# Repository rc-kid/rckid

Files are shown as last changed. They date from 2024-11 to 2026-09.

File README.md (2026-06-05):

# RCKid mk3

RCKid is an open‑source handheld console designed for young creators. It’s built to be the first piece of technology that feels truly personal to a child — not just a screen to consume, but a tool to imagine, build, and share. RCKid also supports kids in everyday tools like a clock, alarm, piggy bank, contacts, or music player. This balance of fun and function turns RCKid into a trusted companion, introducing kids to digital literacy, technology, and STEM skills in a way that grows with them. For more information, have a look at the [grand vision](VISION.md) 

Starting at age 5, kids can design sprites, tiles, and music inside native games, learning problem‑solving naturally through play. As they grow, RCKid will provide more and more complex ways of control (visual blocks, scratch-like blocks, C++, Full C++ SDK). For more details see [development ladder](LADDER.md).

A defining feature is RCKid’s cartridge system — not just for games, but for extending hardware. Cartridges can add Wi‑Fi for messaging, radios for mesh networking, JACDAC peripherals, IR remotes, or even exposed pins for DIY tinkering. Each cartridge carries its own firmware, making creations tangible, shareable, and hackable.

Powered by the RP2350 MCU (dual Cortex‑M33, 520KB RAM, PIO), RCKid combines raw performance with developer‑friendly design. It features a 2.8" IPS display at 60 FPS, stereo audio up to 48kHz, SD storage, RGB‑backlit controls, accelerometer, haptics, FM radio, and flexible power (USB‑C Li‑Ion or AAA batteries). Everything is built to be fun, approachable, and resilient.

## Technical Details

- RP2350 MCU from RaspberryPi that mixes raw power (520KB RAM, 2x Cortex M33 cores at 150MHz with overclocking possibility) and ease of use (C++ SDK, micropython). Further supported by great community and skillfully designed so that programming it is *fun* even for experienced developers (PIO)
- unique cartridge system: the firmware is not stored on the device, but in every cartridge. Cartridges can be swapped, shared, or reprogrammed with any computer easily. On top of the mandatory FLASH for the firmware, cartridges contain 8 high speed digital pins (HSTX, SPI, I2C, UART, PWM) and 2 analog pins to enable hardware tinkering
- 2.8" 320x240 IPS display with 65536 colors. Perfect for retro gaming and pixel art with enough catchy detail, but not too many pixels to design. 60 FPS refresh rate.
- 16bit stereo sound (headphones & mono speaker) with up to 48kHz playback. Powerful enough for MP3 playback
- SD card for media & settings, up to 64GB supported. FAT32 and exFAT filesystem 
- DPAD, A, B, Select and Start buttons with customizable RGB backlight
- 3 axis accelerometer with integrated pedometer
- rumbler for haptic feedback (simple motor)
- FM radio with RDS
- 1300mAh LiIon rechargeable battery with USB-C charging, or 3x AAA batteries, both options should give around 10 hours of active time. 

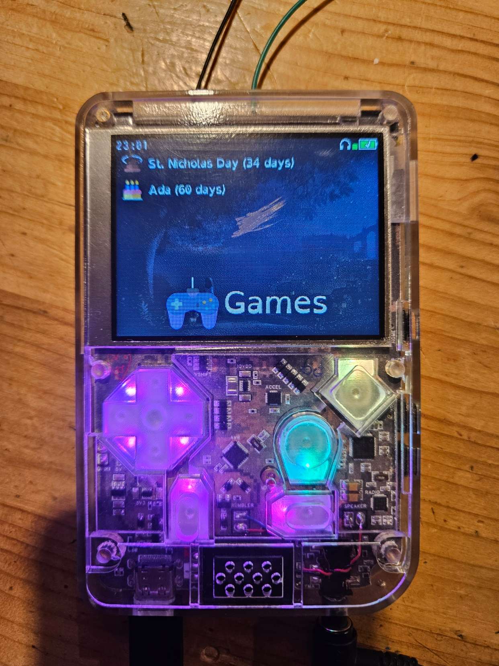
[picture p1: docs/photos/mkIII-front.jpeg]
RCKid mkIII RCKid prototype


## Development

> The readme is mostly about setting the project up and understanding its development & internal structure. 

RCKid supports different backends, including a fantasy backend that allows running RCKid cartridges virtually on the PC, and the mkIII backend that runs on the actual device. Each backend provides its own implementation of the hardware abstraction layer (defined in `sdk/include/rckid/hal.h`) as well as capabilities (see below).  The fantasy backend, also includes test target (`run-tests`) that runs unit tests for the SDK and selected cartridges. It emulates the hardware of the device, including the display & sound using raylib, SD card and LittleFS on the cartridge using dedicated iso files and the FatFS and LittleFS libraries, or native folders via virtual filesystem (where the filesystem API is implemented for normal files, bypassing the fs libraries altogether for convenience). The fantasy backend also supports emspcripten.

## Project Structure

The project is organized into a few top level folders that branch into subfolders where appropriate. This is reflected in the brief list below:

- `sdk` : the SDK code (common firmware for the device, backends, ATTiny MCU, etc.)
- `sdk/assets` : asset files in their natural form (images, sounds, etc.)
- `sdk/backend` : the supported backends (implementation of the hardware abstraction layer)
- `sdk/backend/fantasy` : the fantasy backend for RCKid. This allows running RCKid cartridges virtually on the PC
- `sdk/backend/mk3` : the RP2350 and the device specific code
- `sdk/backend/avr` : firmware for the ATTiny3217 MCU responsible for IO, power management, etc
- `sdk/include/rckid` : SDK headers to be included into cartridges (the SDK API). Some code in this folder, rest in subfolders
- `sdk/include/rckid/apps` : applications for RCKid (pedometer, audio player, clock, etc.)
- `sdk/include/rckid/audio` : audio recording / playback, codecs, etc.
- `sdk/include/rckid/capabilities` : extra hardware capabilities (WiFi, pedometer, flashlight, etc.)
- `sdk/include/rckid/game` : game engine with C++ and dynamic bindings for kids to create their own games
- `sdk/include/rckid/graphics` : basic graphics utilities (colors & representation, bitmaps, fonts, etc.)
- `sdk/include/rckid/ui` : simple UI widgets toolkit 
- `sdk/include/assets` : assets for the rckid converted to constexpr arrays to be included with cartridges
- `sdk/src` : C++ implementation for the files in `sdk/include`, same structure internally
- `sdk/test` : unit tests (see testing chapter below)
- `lib` : contains 3rd party libraries that are copied / cloned as part of the SDK (including pico-sdk and raylib). Do not change code in here except for the platform below
- `lib/platform` : custom headers for different platforms (desktop, rp2350, ATTiny3217, Arduino, ...) for basic HW features and cross-platform utilities
- `cartridges` : cartridges for the RCkid
- `cartridges/text` : cartridges specifically for test purposes
- `gbcemu` : Gameboy emulator implementation for RCKid
- `datasheets` contains copies of datasheets of the hardware used in RCKid
- `hardware` contains hardware related files, such as schematics, PCB layouts and case drawings
- `lego-remote` AVR firmware for a remote client to control lego bricks, at the moment just parked here from mkI

## Important Files

Non-code files:

- `README.md` : basic intro the the repository, build instructions, etc.
- `VISION.md` : the vision for the project, you can read this for context when discussing non-code, but necessary for the code itself
- `LADDER.md` : the learning ladder for the project, which I am implementing in the `sdk/include/rckid/game` folder (from asset editor for youngest kids to visual editor to blocks to code DSL to full SDK)
- `HARDWARE.md` : more details about the hardware design, useful forhardware related questions

Code files:

- `sdk/include/rckid/hal.h` : functions that *must* be implemented by each backend to support the basic features (display, power, sound, io, etc.)
- `sdk/include/memory.h` : own memory management including custom heap on the device and virtual custom heap in fantasy mode to track memory consumption accurately

## Building

Although there is technically nothing that should prevent building the software on Windows, only Linux is officially supported (actually Ubuntu 24.04 running on WSL:). The `setup-ubuntu.sh` must first be executed which installs all the required packages and sets up subprojects, etc. The project uses `cmake` as the build system. Generally I use out of tree builds, which can be found in `build` prefixed folder, such as:

- `build` : for the fantasy target
- `build-mk3` : for the mkIII target
- `build-wasm` : for the fantasy target with emscripten

The build builds all libraries and the creates the executables/uf2 images in the `cartridges` subfolder. `platformio` is used for the ATTiny3217 firmware, which is independent project and can be built using the CLI. Useful source of build information is also the `.vscode/tasks.json` file, which contains tasks for building different targets. It also contains upload targets, which copy the build artifacts to another machine from which they are flashed.

RCKid uses `cmake` so the following builds the fantasy console & all cartridges on linux:

    mkdir -p build
    cd build
    cmake ..
    cmake --build . -j

To build RCKid for the device (mk III in this example), do the following:

    mkdir -p build-mk3
    cd build-mk3
    cmake .. -DRCKID_BACKEND=MK3
    cmake --build .

Finally, to build RCkid for the web using the emscripten toolchain, you can do the following:

    source ./lib/emsdk/emsdk_env.sh
    mkdir -p build-wasm
    cd build-wasm
    emcmake cmake ..
    cmake --build . -j

This creates the demo app in `build-wasm/cartridges/demo`. To view it the artifacts (`demo.data`, `demo.js` and `demo.wasm`) must be copied to `www` folder. Then run http server (wasm cannot be viewed via `file://` protocol). The easiest way to do this is start the following from the `www` folder and then point your browser to `http://localhost:8000`:

    python -m http.server 8000

> Note that emscripten support is now very barebones, I have basically only checked that it works and added the build to CI so that I do not do something to jeopardize it.

### Build Arguments

RCKid's build can be customized using various arguments, such as the `-DARCH` showed above to build for a particular architecture. This section lists other useful build arguments:

- `-DRCKID_WAIT_FOR_SERIAL` runs RCKid to the end of the initialize() function and then waits for a single byte to be sent on the USB-Serial. This is useful to ensure that a serial monitor on the pc is up & running before RCKid's firmware starts doing stuff so that it can be captured properly.

## SDK

The SDK library is at the core of RCKid as it provides an abstraction layer over the console's hardware. Furthermore, it makes RCKid also a fantasy console by being able to run on a PC for most of the features. Therefore the SDK comes in two folder, `rckid` where the common interface resides, and `backends` where specific implementation for the various hardware versions and fantasy consoles is implemented. 

> For now, fantasy console via raylib (Windows and Linux) and  RCKid mk3 (RP2350) are supported. There are plans for future platforms & variations. Note that the fantasy platform is mostly for debugging only.

## Debugging on the Device

    sudo apt-get install pkg-config libjim-dev libudev-dev
    git clone https://github.com/raspberrypi/openocd.git
    
    cd openocd
    ./bootstrap
    ./configure --disable-werror --enable-sysfsgpio --enable-bcm2835gpio
    make -j4
    sudo make install

Connect the SWD port for the RCKid (on devel-server the wires are, from top to bottom, looking from the back, from top to bottom):

         | GND   |
    -----|-------|---------
    blue | green | yellow

Then run openocd on the rpi with the following command:

    openocd -f interface/raspberrypi-swd.cfg -f target/rp2350.cfg -c "adapter speed 5000" -c "bindto 0.0.0.0"

And to run the debugger, can run gdb from the computer that compiled the cartridges:

    gdb app.elf
    target remote IP_ADDR:3333

Where `IP_ADDR` is the IP address of the rpi server. 

    monitor reset init

(from https://betanet.net/view-post/using-openocd-on-raspberry-pi-4-a)

### AVR Serial TX

AVR does not support on-chip debugging, but to provide at least some debugging hints, the TX pin is available on the debugging header together with AVR UPDI and RP SWD pins. To connect to it connect the TX pin (green cable in devel-server case) and then launch picocom at 115200 baud:

    picocom -b 115200 /dev/ttyAMA0

Where `/dev/ttyAMA0` is your USB device, this one is the default with devel-server. 

> To exit picocom, use C-A C-X. 

### Debug Cartridge

For easier debugging, the debug cartridge has protruding wires to some of the GPIO pins available, namely:

Wire Color | Function
-----------|-----------
Black      | GND
Red        | 3V3
Green      | GPIO 12, UART0 TX
White      | GPIO 13, UART0 RX
Blue       | GPIO 14
Yellow     | GPIO 15

## Attribution

- doxygen theme: https://github.com/jothepro/doxygen-awesome-css
- icons are from flaticon, for detailed attribution, please see ATTRIBUTION.md file

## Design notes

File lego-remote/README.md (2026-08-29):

# LEGO Remote Controller for RCKid

> This is verbatim copy of the code I created a while ago for mkI. It should be restructured and updated to the mk3 code. Consists of the firmware for the arduino, the remote.h protocol specification and the lego-remote.h device configuration. 

## Pairing

The control brick is very dumb and does not have any internal state (apart from its name) that would survive power cycle, all is managed by the remote. The handshake looks like this:

                              Controller | Remote
                         --------------- | --------------
                                         | L: (listen for new devices - optional) 
    B: broadcast its name on set channel | 
                                         | P1: send pairing info on set channel
                                         | (own name & channel, wait for ACK)
                                         |
            switch channel & wait for P2 | switch to channel, send P2, wait for ACK
                                         |
         (timeout 1 second, return to B) | (timeout 1 second, return to L, or P1)

While pairing the controller flashes red lights. When paired, blue is flashed. Upon pairing the remote uploads the connector profile, after which the pairing is complete. 

While paired the remote periodically updates the controller every 1/100th of a second (10ms). If there is no update for 50ms the controller enters the disconnected state, in which case all motors are powered off and lights flash red. Upon regaining connection, the remote must acknowledge the disconnect before the motors can be powered on again. 

## Power

The controller brick operates from any voltage between 5 and 9 volts, inclusive. It uses a special connector that supports connecting 2 Li-Ion cells in series as well as other configurations:

    1N    2P  
    1N 2N 2P
    1P 1P 2N

Internally the `1P` and `2N` terminals are connected together to provide 7.4V between `1N` and `2P` which should be used for other sources. 

The controller consists of ATTiny, radio and the following:

- 2 motor drivers (5 or 9volts)
- 5 extra peripherals

- motor driver: 2x https://www.pololu.com/product/2960
- 9V stepup: 

## Connectors

The connectors are built from headers, in a way that supports all possible orientations by doubling the pins. 

### Motors

Motors use 3x4 12pin connector that allows the motor to select its own voltage as well as draw voltage for electronics. 

    5V   +   -   9V
    SEL GND GND SEL
    9V   -   +   5V

### I/O

This includes Speaker, RGB lights, buttons... Arranged in 2-1 in a row. 

    5V    X
    GND GND
    X    5V

### Expander

The expander connector is a 7pin 3x2x3 connector with the following layout:

    SDA     SCL
    5V  GND  5V 
    SCL     SDA

> TODO should there be I2C connector? 

## Peripherals

Internally there will be two INA219 for measuring the current on the attached motors. An accelerometer is also a possibility. 

> See if I have enough accels and other useful I2C parts. 

### LEGO 4.5V Motor

Uses the motor connector, 5V input. 

### LEGO Power Functions 9V Motor

Uses the motor connector, 9V input. 

### LEGO NXT Motor 

Uses the motor connector, 9V input. Additionally can use up to 2 peripheral connectors for the speed control. 

- 1 (white) Motor PWR 1
- 2 (black) Motor PWR 2
- 3 (red) GND
- 4 (green) ~4.5V
- 5 (yellow) Encoder 1
- 6 (blue) Encoder 2

### LEGO Compatible servo

Uses the peripheral connector in servo mode. 

### PWM Speaker

Uses a dedicated peripheral connector that is wired to PWM supporting pin. 

### RGB LEDs (chainable)

Uses a peripheral connector

### Button (chainable)

Uses a peripheral connector. Chaining works as or so that any chained button press will register as press. 

# Remote Protocol

# RCKid Remote Protocol

A simple and extensible protocol that allows the RCKid to use its onboard NRF radio to remotely control various devices. The RCKid acts as a _remote_ that can control an arbitrary number of _devices_. Each device has a number of _channels_ into which all the device's functionality has to be encoded. The remote protocol supports pairing, querying devices and their channel capabilities and so on. 

> Note that the protocol is very simple and its main purpose is *not* security. 

## Channels

A client device is described by a list of channels. Each channel has a specific type and consists of the following distinct parts:

- _control_, which is information the remote communicates regularly to the device that alters the state of the channel (such as motor speed)
- _feedback_, which is information the device communicates to the remote, such as current consumption
- _config_, which consists of channel configuration that is not expected to be changed once the remote and the device are paired, such as the motor's current limit

Each part of the channel can be empty, depending on the channel type. Channels are identified by numbers from `1` to `255` inclusive. The following channel types are supported:

### Motor channel

The motor channel provides control for single DC brushed motor attached to an H bridge. It consists

### CustomIO

A configurable channel that can fit multiple purposes. Corresponds to a single wire and various digital/analog functions it may have, namely:

Mode              | Control   | Feedback | Config
------------------|-----------|----------| -------------
Digital Out       | 0/1       |          | 00
Digital In        |           | 0/1      | 01
Analog Out (DAC)  | 0 - 255   |          | 02
Analog In (ADC)   |           | 0 - 255  | 03
PWM               | 0 - 255   |          | 04
Servo             | 0 - 65535 |          | 05 iiii xxxx
Tone              | 0 - 65535 |          | 06

### ToneEffect

### RGB Strip

The RGB strip channel is designed to configure and control a strip of RGB colors such as neopixels. The config part of the strip is the index of the first RGB channel specifying the color and the length of the strip. The length of the strip should not exceed the number of RGB colors available. The is no feedback and the channel control is the state of the strip, which can be one of:

ID   | Meaning
-----|-------------------
`00` | Manual control - the strip will display exactly the colors specified in the RGB channels
`..` | Effect - the number specifies which effect to use

### RGB Color

Single RGB color. Its control cosists of the three RGB bytes. No feedback or config is possible. The purpose of the RGB color channel is to simply hold memory for one neopixel. The device itself and the RGBStrip channel's config the determine which of these colors will be used. 

## Communication

## Commands

By default the remote sends the device channel control information and the device sends back the channel feedback info when there is change. Instead of sending directly the channel data, the remote may choose to send one of the predfined commands instead:

`00 00` - Heartbeat

`00 01 xx` - Read feedback of channel `xx`

`00 02 xx` - Read control of channel `xx`

## Notes

Can use https://jlcpcb.com/partdetail/Mixic-L9110S/C513306 for the HBridge, or maybe even better this one: https://jlcpcb.com/partdetail/Bardeen_Micro-BDR6125/C5349300, which is rated for 3A, which is plenty for my needs.

Try PUYA chips as well for lower costs and same architecture across the ecosystem

3x INA219 (main + m1 + m2)
2x Hbridge
2x 5V step-down
1x MCU

- use SMT female headers to have more PCB area on the back for the connectors

- an idea: add JACDAC port and make the lego brick a simple peripheral that just exposes the attached devices as JACDAC ones so that the brick can work with JACDAC ecosystem as well

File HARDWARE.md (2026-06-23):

# Hardware Design

> This is hardware description of RCKid mk III (version 29/7/25 and above). For brief history and to clear any confusion, mk I was much larger, hand soldered version powered by Raspberry Pi Zero 2W and mk II was slightly slimmer version powered by RP2040 with 8bit parallel screen interface.

RCKid is based on the [RP2350B](datasheets/rp2350-datasheet.pdf) (80 pin QFN) and uses its requirement for external program flash chip as a feature by allowing swappable cartridges. This is the overall architecture of the system:
          
                                              +-----------------+
                            + --------+       | Cartridge       |
                            | microSD |       | (flash, extras) |======\\                              
                            +---------+       +-----------------+       \\ (analog audio input)
                                   \\\\       ////                       \\                   
                          <SPI/SDIO>\\\\     ////<8pin/HSTX,2/ADC,QSPI>  ||                        
                                     \\\\   ////                         ||                 /---- speaker
                                     ||||   ||||                         ||                /
       +-----------+  <16bitMCU>   +-------------+     <I2S>       +---------------+      / (analog mono)
       |  ST7789V  |===============|   RP2350B   |=================| NAU88C22GY    |------
       | (Display) |               +-------------+                 | (audio codec) |_____   
       +-----------+                     ||                   //===+---------------+     \ (analog stereo)
              |                          ||                  //                           \  +------------+
              | <PWM>                    ||                 //                             \-| 3.5mm jack |
              | (Backlight)              ||================//                                +------------+
               \                         ||
                \                        || <I2C>     
                 \                       ||           //======(buttons, 3x4 matrix)
                  \               +-----------------+//
                   \              |    ATTiny3217   |/
                    \-------------| (IO, time, pwr) |----------(RGB)
                             /----+-----------------+
                            /           /|\        \     +-----------+
             (rumbler)-----/     <I2C> // \\        \----| MCP73832  |----(battery)
                          <PWM>       //   \\            | (charger) | 
                            +----------+   +----------+  +-----------+
                            | LSM6DSV  |   | LTR390UV |
                            | (Accel)  |   | (light)  |
                            +----------+   +----------+

Next to the control & logic elements above, there are also various power rails, their short description is below:

- `VUSB` is the +5V coming from the USB port, active when USB is connected, used for charging
- `VBATT` is the battery terminal 
- `VCC` is the main system rail. This comes either from the battery, or from the USB when connected. Valid voltages are from 3v to 5v. This rail is measured by the AVR to determine battery status / USB presence and is fed to the 3 DC-DC converters below:
- `3V3` and `IOVDD` are identical buck-boost converters to 3v3. The `3V3` rail is always on and powers the AVR, accelerometer, display backlight and rumbler. The `IOVDD` can be enabled by the AVR and powers the RP2350B, cartridge and audio system
- `5V` is a charge pump to 5V required by the RGB lights (controlled by AVR)

## I2C Bus

Most of the perihperals are connected to a single I2C bus. The pull-ups of the bus go to the `IOVDD` so that the bus is only working when the device is on. To make sure eveything works, before AVR turns `IOVDD` off, it emits `START` condition on the bus, which is followed by `STOP` condition transmitted right after `IOVDD` is enabled back. 

### Sensors

The only extra sensors in mkIII are the onboard acceleromeneter [LSM6DSV](datasheets/lsm6dsv.pdf) and ambient & UV light detector [LTR390UV](datasheets/LTR_390UV_Final_DS_V1_1.pdf). 

LSM6DSV is relatively simple to use (similar to the discontinued BMI160 used in mkII). As it is also capable of working as a pedometer, it is always on, connected to the `3V3` rail. The accelerometer has its interrupt connected to AVR so that we can intercept taps, steps, etc.

The ambient light detector does not have its interrupt pin connected and must be polled.

Furthermore several of the devices connected to the I2C bus also supoort temperature measurements (including the AVR itself).

## Power Management

Power management consists of a standalone Li-Ion battery charger [MCP73832](datasheets/MCP73832.pdf) and a power path via a MOSFET and diode that enables DC power when connected, and battery otherwise. MCP73832 *must* be used as the AVR runs on 3.3V while the charger runs at 5V so outputting charger high when charge is complete as the 73831 does could destroy the chip. There is no such danger with MCP73832 as the STAT pin behavior is HiZ when not charging and low when charging.

The charger pinout is as follows:

- `VDD` is connected to the VUSB (5v)
- `STAT` is the charger state output (low when charging, floating otherwise)
- `VBAT` goes to the battery
- `PROG` is connected to `2k2` resistor for `???` max charge current

The AVR monitors the `VCC` rail (after power path), which enables it to determine battery voltage when powered from battery (value <= `4.2V`) and if USB is connected (VCC above `4.2V`). This is done through a `100k/200k` voltage divider that is always on. This seeps negligible battery power and is above the `50k` input impedance of the AVR adc, but we compensate for this by longer capture times. Charger status is monitored via the `STAT` pin that is connected to a `100k/200k` voltage divider on the `VUSB` (so that it is pulled high at `3v3` when USB connected, `0` otherwise). As per the datasheet, the `STAT` pin is floating when not charging and goes to `0` while charging. This gives the following power scenarios:

- `VCC<=4.2V` battery is connected, `STAT` should be 0 (but can really be ignored)
- `VCC>4.2V` and `STAT` is low means USB is connected and the device is charged
- `VCC>4.2V` and `STAT` is high means USB is connected, but charging is done

### Li-Po Battery

By default the device runs from a LiPo battery such as [503759](https://www.tme.eu/cz/details/aky-lp503759/akumulatory/akyga-battery/aky0107/).

### Running from AAA batteries

The device also supports a different configuration when it can be powered via 3 `AAA` batteries in series. This gives maximum voltage of `4.5V` (for alkaline, will be around `3.6` for NiMH) and minimum voltage can go *very* low for alkaline, or about `3V` for NiMH. In those settings the cutoff voltage is defined by the minimal input voltage of the DC-DC regulators, and particularly the `5V` charge pump, whose minimal voltage is `2.7V`

To enable the `AAA` mode, the charger chip simply should not be soldered. 

> If the batteries are replaced while the device is powered by USB, there is no data loss wrt timekeeping, or user information. 

> The plan is to use clip-on contacts on the batteries for lowest possible clearance, those will be added to two extra pcbs that will slide to the extended case and connected by wires to the +/- BATT terminals

### 3.3V Buck-Boost converters

The design uses two identical step down converters - [TPS631000](datasheets/tps631000.pdf). This is newer chip than the original designs in mkII and devboard and provides greater efficience and range. As per its datasheet, it is capable of providing `800mA` in boost mode (and `1.2A` in buck), which is within the limits (500mA cartridge + 300mA for RP2350B and audio is the limiting factor here). 

The converter is variable output resistor configuration straight from the datasheet is used for `3v3` output. So is the inductor and the recommended layout. The two DC-DC blocks are almost identical with the exception of the on switch, which for `3v3` is tied to input voltage for always enable, while for the `IOVDD` is pulled down with `100k` resistor for default off behavior and will be pulled high to `3v3` by the AVR when enabled (this is well above the logic high threshold for the chip at `1.2V`. The chip tolerates up to `7V` on the `EN` pin regardless of the input voltage, so even with very low VCC (technically we can go as low as `2.4V` the chip will work).

### 5V Charge Pump

We are using [HX4002](datasheets/hx4002.pdf) charge pump, same as in mk II. The pump is capable of delivering in excess of 240mA for 3.6V input voltage (it runs from VCC, which is stepped up above 3.3v). It only powers the [RGB leds](datasheets/rgb.pdf), which take at most 5mA per channel, which gives us 120mA when at full power.

### Power Consumption

To share the load between the two DC-DC converters, teh display backlight and the rumbler (which can separately be turned off) are connected to the `3V3` rail. The `TPS63001` is very effective at high loads, so we assume `90%` efficiency (will be a bit higher in reality). The calculation for the maximum power that can be drawn from the battery at the lower acceptable level (`3V`) is thus:

    MAX = (800 * 3.3 / 3.0 / 0.9 * 2) + (240 * 5 / 3 / 0.8)
    MAX = 1955 +                        500
    MAX = 2455 [mA] @ 3V

For a more realistic example, let's assume full utilization of the `IOVDD` converter (i.e. 300mA for the RP2350 and 500mA for the cartridge), 110mA utilization for the `3V3` converter (100mA brightness, 10mA for rumbler as mostly off), and 50mA for the RGBs (red at 50%):

    REAL_MAX = (800 * 3.3 / 3 / 0.9) + (110 * 3.3 / 3 / 0.9) + (50 * 5 / 3 / 0.8)
    REAL_MAX = 977                    + 134                   + 104
    REAL_MAX = 1215 [mA] @ 3V

This is within the `1C` discharge rate for the battery, which is good. 

## Audio

[NAU88C22GY](datasheet/nau88c22gy.pdf) chip is used, which is relatively simple, yet it offers all the features we need - 16bit audio playback & record, line-in for the radio, microphone input, integrated headphone and mono speaker (BTL) drivers. While the chip features audio jack detection and can automatically enable/disable headphones based on the jack status, it does not offer any way to report the jack status, hence the jack detection pin is shared with RP2350 which can read it. The chip also provides no interrupt (no events available) and provides one simple digital GPIO that can be set high or low (not used). In terms of I2S, the chip requires MCLK to be provided, but it does not have to be of the exact frequency needed as the internal PLL can adjust it - but we are not using this feature. Pinout:

- `VDDA`, `VDDB`, `VDDC` and `VDDSPK` are all connected to the `IOVDD` 3v3 rail for simplicity, decoupled with `4u7` caps
- `VSSA`, `VSSD` and `VSSSPK` are all connected to `GND`
- `SCLK` and `SDIO` are connected to `SCL` and `SDA` respectively via a `220` resistor and `33pF` capacitor, as per the datasheet to add filtering to the lines
- `FS`, `BCLK`, `ADCOUT` and `DACIN` are connected to the `I2S` bus
- `MCLK` is connected to the master clock generated from the RP2350
- `LHP` and `RHP` are connected to headphones via large `220uF` capacitors
- `LSPKOUT` and `RSPKOUT` are connected to directly to the speaker in BTL mode
- `RAUXIN` and `LAUXIN` are connected via `1uF` capacitors to the radio analog output (as per the datasheet)
- `LMICP` and `LMICN` go to positive and negative microphone terminals via `1uF` capacitors (as per the datasheet)
- `MICBIAS` is connecte to ground via `4u7` capacitor and to positive mic input via `2k2` resistor (as per the datasheet)
- `RMICP`, `RMICN`, `AUXOUT1` and `AUXOUT2` are left floating (as per the datasheet for unused analog inputs/outputs)
- `GPIO2` goes to headset detection
- `GPIO3` is tied to ground as per the dataset for unused gpio
- `MODE` is tied to ground for I2C selection

> Note that I2C communication with the chip did not work when MCLK was being generated on the breadboard. This was fixed by adding the RC filter to I2C lines as per the datasheet (220R, 33pF). 

#### Microphone

As per the typical application, the microphone is connected differentially to `LMICP` and `LMICN` with `2k2` from MICBIAS to positive mic, 0.1uF capacitor on the positive output to right channel and direct connection to ground on the negative channel, which also goes to the left input via 0.1uF capacitor.

> TODO Verify the microphone works

#### Headset detection

Headset detection is via a `100k` resistor to the `IOVDD` line to second ground terminal of the headphone jack. This will read high when headphones are not detected and will go to `0` when headphones are inserted as the ground will be connected to both terminals. The headset detection line is then fed to the audio codec for automatic speaker/headhone switching and to the RP2350 as well to determine the headphone status. 

We use two switch, 3 contact [headset connector](datasheets/headphone%20jack.pdf), half sinking for better profile. 

> TODO the pullup is wrong (too high) and also, maybe by connecting tip with some large resistor to 0 (68k or so) and then connecting the tip mate via even higher resistor to VCC as a pull up. Then it will read close to 0 when not inserted and VCC when inserted. But will this upset the audio? It actually might work and I can ignore the second sleeve and it would work with all headphones! (can I make it work with current audio setup by rewiring?)

## AVR (ATTiny3217)

[ATTiny3217](datasheets/ATTiny3217.pdf) is used in QFN package and is responsible for power management, input & output (buttons, rumbler and display PWM) and some sensors (RTC clock, temperature sensor). All pins are used, the AVR_INT pin plays double duty as AVR interrupt to RP2350 and serial TX from the AVR chip for debugging (on RPI the pin matches alt UART0 RX). The chip also runs from 3.3V as well, so it can't use VCC measurement to check battery levels (instead it uses dedicated 100/200kOhm divider into a pin for voltage measurements. Pinout is as follows:

- display backlight PWM on `PC0` (TCB0 WO alt)
- rumbler PWM on `PA3` (TCB1 WO)
- I2C SCL and SDA on `PB0` and `PB1` (default)
- AVR_INT (and TX) on `PA1` (UART TxD alt)
- 32.768kHz ext oscillator at `PB2` and `PB3`
- VCC_SENSE at `PA2` (which is AIN2 for ADC0 in AAA battery mode)

Remaining functionality is interchangeable as they are used simple digital pins, namely:
- BTN_1, BTN_2, BTN_3 and BTN_4 for button matrix rows (`PA6`, `PB7`, `PA7` and `PC2` respectively)
- BTN_DPAD, BTN_ABXY, BTN_CTRL for button matrix cols (`PC4`, `PB6` and `PB5` respectively)
- ACCEL_INT (input from accel) at `PB4`
- CHARGING detection (low when not charging, high when charging) at `PA5`
- IOVDD_EN and 5V_EN for IOVDD and 5V power rails at `PC1` and `PA4`
- RGB for neopixel control at `PC3`
- QSPI_SS, connected to RP2350 QSPI_SS pin to boot into bootloader at `PC5`

### Buttons

Due to low number of pins available, a classic button matrix is used. Buttons are grouped in three columns: DPAD, ABXY (A B Sel and Start, historically) and CTRL (home, vol up & vol down). When the device is power off, the CTRL is the only active group so that Home button interrupt works.

### RTC

In mkII the internal oscillator was used for RTC which led to inaccuracies of up to 10 minutes per day. This time we are using external 32.768 kHz oscillator for better accuracy. The crystal load capacitance per the datasheet (page 511) is max 12.5pF which is the value used, so the same circuit as for the radio should work. 

### Rumbler

Rumbler is connected to 3V3 and triggered by AVR PWM. Protective diode is used as well. 

## RP2350B

[RP2350B](datasheets/rp2350-datasheet.pdf) - 2 Cortex M33 core @150Mhz, 520KB RAM, PIO and so on. Arguably, there are chips that are more powerful (high-end STM, ESP32 would provide WiFi for "free"), but none I have tried beats the fun of programming RP2350:) So I am sticking with it. Further details of how the HW requirements for the chip should look can be found in [HW Design Notes](datasheets/hardware-design-with-rp2350.pdf). Basic pinout is below, for more details see the desciption of subsystems below

- I2C SDA & SCL (gpio `0` and `1`)
- Radio interrupt (`2`)
- AVR interrupt (and debug UART TX) at `3`
- I2S MCLK at `4` (its own pio sm)
- I2S DIN, DOUT, BCLK and LRCLK (`5`, `6`, `7`, `8`) (record & playback sms)
- HEADSET_DETECT (`9`)
- SD_CD (card detect) `10`
- display RDX at `11`
- cartridge HSTX (`12`-`19`)
- display DB15-DB0 (`20`-`35`)
- display WRX, DCX, CSX (`36`, `37`, `38`)
- display TE (input at `39`)
- SD card SCK, TX, RX, SDIO1, SDIO2 and CSN (`40` - `45`)
- cartridge ADC (`46`, `47`) 

### USB

Using jlcpcb impedance calculator and 1mm thick board with coplanar differential pair (coplanar because it is bordered by GND on the top layer as well), we get trace spacing of 0.2mm, trace to ground spacing of 0.254mm and trace width of 0.156mm for the USB required 90 Ohm impedance.

### I2S

I2S connection to the audio codec is done via LRCLK (FCLK), BCLK and DIN & DOUT pins for playback and recording respectively. Furthermore MCLK has to generate steady clock at 256x the framerate (LRCLK) for the codec to operate. 47Ohm terminating resistors are used for all the I2S lines and MCLK.

### SD Card

Although the SD card supports SPI protocol, in is not connected to any of the HW SPI pins. Instead connection scheme that will work for SDIO (with the data pins being sequential) is used and a dediacated SPI PIO will be used for the SPI comms. This allows device to later support the faster SD interface instead. 

SD card detect works ising internal pull-up on the `SD_CD` line. When no card is present, it will read high, but when card is inserted this is connected to ground and will read low. The internal pull-up is high enough to make the power draw for this negligible. 

### Display

[ST7789v](datasheets/ST7789V.pdf) in 16bit parallel MCU interface is used with FPC connector for easier assembly. The display uses both power supplies, `IOVDD` for the digital interface and `IOVDD` for backlight. This allows for a better load distribution (otherwise the `3v3` always on SMPS has not much to do most of the time with only the AVR connected). The display uses 16bit parallel interface to speed up the data transfer process, which is extremely useful especially in framebuffer applications. The RDX line is also available so that the CPU can read from the display as well (can be used in the future for visua effects). 

For backlight, we use [AP2502](datasheets/AP2502), which can sink up to 80mA of current in total of 4 channels. This is less bright than the max of 100mA recommended by the display datasheet, but is still comfortably high. 

## Programming & Debugging

The device provides 2 programming & debugging ports for the AVR and RP2350 chips. The RP2350 uses the standard 3pin SWD interface known from the Pico boards. The AVR chip has a 2 wire UPDI programming interface (UPDI & GND). Both are unpopulated, but as they use standard 2.54" spaced holes, they can be populated with connectors and are located in places where case cutouts can be made for easy access.

> TODO in the future, if we use I2C bootloader for the AVR chip, there should be no need for an user accessing UPDI connector any more, but maybe it is still convenient to have.

## Test Points

- `SDA` and `SCL` lines for I2C
- `INT/TX` for the AVR_INT/TX line to be able to debug the AVR chip

## DFM & DFA

At this stage the PCB is still fairly prototype stage as there is a reasonably high amount of hand soldering and careful steps to manufacture & assemble the device:

- the biggest problem is probably the custom cartridge connector which consists of a separate board and has to be hand soldered. For a large run - perhaps a better spring contact can be found that can attach to the bottom of the PCB and can be soldered automatically with 2 sided assembly
- bottom side buttons - will be fixed by 2 sided assembly
- battery connector is again a custom PCB connected via hand soldered wires and connectors. If we get battery with standard connector, this too can be fixed by a bottom side soldered connector (another option would be to use cell phone batteries)
- speaker - requires soldering of the wires, maybe for plarge production can use speaker that has spring contects to the pcb (but how would the sound box work?)
- rumbler - can be had with connector in large quantities

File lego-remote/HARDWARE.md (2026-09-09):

# LEGO Remote Brick Hardware Specification

> This document describes the second iteration of the remote brick that uses RP2040 as the brick MCU, which gives much nicer programming interface than the original ATTiny3217. 

## Power Domain

Battery goes via a polyfuse to the battery charger's battery port as well as to the global current sense resistor towards the motors 5V regulators. The VSYS regulated path of the battery charger goes to the 3v3 regulator used for system rail. This is to ensure that system is always on even when battery is charged, while the firmware must ensure that when battery is being charged, the 5V regulators as well as motors are powered off. 

### Battery Charger

We use Monolithic MP2672A which is an integrated 2S li-ion charger in standalone mode so that any RP2040 firmware glitches cannot interfere with the charging:
- `CV` pin pulls to GND with `33k` resistor to select 8.4V battery chemistry (the safest)
- `ILIM` pin pulls to GND with `12k` resistor for 1A charging
- `VLIM` is set to 4.5V minimal charging voltage by having RH 33k and RL 12k.

### Left and right 5V

Two buck converters to 5V, 2A each are provided for the left and right side connectors (2 general and 1 motor per side). 

### 3v3 System Power

### Current Sensing

INA219 is used three times, one global for total consumption of the entire brick, and 2 for left and right motors respectively. INA219 senses both voltage *and* current so we also know the battery level and the selected motor voltages. 

### Power Envelope

> TODO

## Radio

> TODO

## Motors

Left and right motor drivers are available both with voltage selection (directly from the battery, or 5V from DC-DC converter), INA219 for current sensing and a full H bridge for motor control. 6 row reversible hedaer connector allows the motor itself to determine the voltage by routing it from full/5V to VSEL which then goes to the current sense and H bridge motor power.

## General Pins

2 left and 2 right general pins are available. They provide 5V, GND and DATA in a reversible 3 row connector. The DATA pin goes directlyto the RP2040 and as such is expected to be between 0..3.3V. The use of general pins is completely up to the firmware, but we ensure the connections go to the ADC pins so that analog input is possible.

## BOM Optimization

Run everything off a single 5V rail rated at 3A 

- https://jlcpcb.com/partdetail/SilergyCorp-SY8366HQQC/C178253 is 5V buck converter rated for 6A, will power everything
- https://jlcpcb.com/partdetail/TexasInstruments-INA180A3IDBVR/C122882 for each motor *and* gpio, as well as one for the total output, all connected to
- https://jlcpcb.com/partdetail/TexasInstruments-TLA2528IRTER/C2866175 which is 8 channel ADC

- should be cheaper BOM I would think... Let's check

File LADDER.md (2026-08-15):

# Programming Ladder

This describes the core ideas behind the programming ladder built into RCKId's SDK that enables on-device application programming and algorithmics across wide age & skill ranges. This is powered by a single DSL that is exposed to the users via different editor levels and capability tiers. Think of this as more fine grained and on-device oriented MakeCode (which already switches between blocks and TypeScript) combined with Hedy levels. Not very editor supports every level, but the exact level & editor boundaries are not in the current scope of this document. 

The different editors are the cornerstone of the entire design. They support the users across the wide range of cognitive and literacy skills. The editors and their on-device capabilities shape the language design itself (and its levels) and give children agency as especially younger kids generally lack unconstrained access to a PC: 

    Editor        | Host   | Literacy | Description
    --------------|--------|----------|-------------------------------------------
    asset editor  | device | pre      | Edits app static assets (images, sounds, tilemaps, etc.)
    iconic editor | device | pre      | Edits parts of code with iconic representation via chevrons
    visual editor | device | lit      | Edits code via chevron based visual blocks (Scratch for small screens)
    token editor  | device | lit      | Edits code with input terminal by terminal (for on-device text editing)
    text editor   | pc (*) | lit      | Edits code as normal text editor does (can produce invalid programs)

> (*) This is mostly because editing character by character on device without qwerty keyboard is really painful. I am however considering an RCKid mod where something like blackberry keyboard can be overlaid over the PCB for a full keyboard experience after which the text editor can easily run on-device. 

All editors are just projections into single language and runtime shared across all levels. This ensures that as the children move to more complex levels and editors, they can take their creations with them, not leave them behind. 

The design also emphasizes extensibility and encapsulation. Children can naturally wrap more advanced functionality into simpler snippets that can be physically shared with peers (via cartridges) and used in their designs. As a simple example, a control flow requiring mechanics can be encapsulated into action and used by people at lower levels where the action hides the control flow. When the users advance to control flow, the so far hidden control flow will become visible and editable. 

> Another example can be adding an icon to the action can make the action (or existing action without an icon) available in the pre-literate iconic editor as well. This allows literate child to empower pre-literate friends.

# Runtime

The prgram is a collection of *game objects*, which are either provided by the SDK itself, or can be created in the DSL itself at more advanced levels. Some game objects are always present (such as Device), while others must be created explicitly. 

Game objects have events and actions (like say slots & signals in QT) and free functions that do not belong to any game object are also possible. The bulk of the program is then connecting game object events to desired game object actions (or ad hoc functions). 

Each game object also defines its *assets*, such as music, sprites, tilemaps and tilesets, etc. Assets themselves are game objects and so new assets can be instantiated (so that sprite game object can swap bitmap assets, etc.). 

The language is always interpreted so that device re-flashing is not necessary and special care is taken in the runtime design to place as much of the immutable data as possible to flash memory as opposed to relatively scarce ram. 

> Note to self: I have proof of concept of RTTI descriptors in flash, but need to verify this works for extensions and objects created at runtime in the DSL itself as well (here they will be obviously in RAM, but should work the same).

The runtime is event based where game objects can also define their *events* and *actions*, akin to signals & slots in QT. An action is simply a method of the game object that can be called as a function. An event can either be assigned a handler function, or be called like a method, which raises the event and calls the handler (*).

> (*) should events be single handler, or should multiple handlers be allowed?

# Editors

All programs are stored in their canonical form with is the text editor's character by character representation (normal text). The editors operate on a grammatical and semantic subset of the full language, which they visualize to fit their needs (such as prefix expression notation in the visual editor, etc.)

This has some important consequences for the game development:

(1) The work done at the lower levels does not have to be lost when the user advances to next representation - each layer is a superset of the layer beneath it, e.g. the visual editor can show everything the iconic editor can, etc. This means the games grow with the children, such as the beaver game used in the examples below. 

(2) Single game does not have to exist at single level. Of course the assets will always be assets, but even the iconic/visual/text can change from event to event based on the complexity of the events, or merely the time at which it was touched.

(3) Work done at higher abstraction levels (and presumably editors) can be encapsulates into blocks available at lower language levels/editors. This can have multiple forms, such as for instance, providing an icon (via the asset editors) for some action/event that does not have one, and thus enabling the even in the iconic editor, encapsulating control flow into an action so that it can be used in non-control flow enabled levels, etc.

> The ultimate extension is creating new game objects using the C++ and the SDK itself. While I am not expecting the students will do that, it is very useful for extending the runtime in capabilities both software (new rendering techniques), and in hardware (game objects for peripherals, etc.).

Unlike the traditional languages, due to RCKid's limited hardware capabilities (especially screen estate, and number of input keys), the editors shape the language itself. Furthermore the editors are designed so that every new editor level requires more abstract thinking from its users, while being able to express more complex code.

## On-Device Editing

RCKid with its small non-touch screen and very limited input controls cannot use the default text editing with character by character typing on the keyboard, nor can it support the drag & drop user interface known from visual editors running on PC or tablets such as Scratch or Makecode. 

Instead, the iconic, visual and token editors all work around the same principle of showing the code in blocks (icons, visual blocks or tokens) with holes (denoted as `...` in the examples below) in the visualized code at places where new stuff can be added. Particular block or hole can be selected via dpad and it can be changed/filled by invoking a context menu, which will show options valid for that block (and possibly change the blocks around it as necessary).  

The hole based on-device editing works the best in prefix notation, whereas the hole is filled with the function/operator, which also knows how many new holes are necessary. This also avoids the clutter of parentheses, which are now not necessary. 

> I am not sure if this is the best way to go forward, but I am nore and more willing to try it out. The language itself does not have to ne prefixed and the text editor (latest tier) can be infix based with the lower tiers automatically converting to prefix.

## Asset Editor

Each game object in the program defines assets it uses. Editing this collection requires no programming/algorithmics skills. Yet it gently teaches basic decomposition strategies (sprite is collection of pixels, sprite animation is sequence of images, music is sequence of notes, tilemap is 2D array of tiles, etc.). In terms of the language, assets can be thought of as static constexpr data (*), which can be edited in the corresponding editors. 

This is a *safe* tier as it only allows changing the looks of the game, not the code itself. Furthermore the tier is pre-literate in its nature.

> (*) Instead of polluting the codebase with static arrays describing the binary data, I am thinking of either some specialized constructors (like say the SDK allows editing pixels in fonts & tilemaps), or even offsetting to external files, which the asset editors can edit. 

> For a specific example, consider a simple platformer. The game mechanics (what happens when buttons are pressed, that a player exists, enemies exist, interaction between them, the platforms in the level themselves) are all defined at the asset level, which also defines which sprite animations and other effects & visuals are required to run the game. Kids can only change those visuals, so instead of say "Mario", you can have a Beaver, instead of platforms you can have lakes with logs and dams, and instead of turtles you can have wasps. The music and sound effects can be different too. But the beaver still jumps and walks like mario and the enemies still walk the same and they all kill the player upon touch

## Iconic Editor

The iconic editor is identical in form and function to the visual editor with single difference and limitation: Instead of text, all actions, events and types are visualized using their icons. This also limits the scope of the editor as actions, events, types, values, etc. that do not have corresponding icons defined cannot be used at this level.

The iconic editor is basically a simple *when-do* style programming based on the game object's event system that should be very easy for children to understand even at pre-literate stage.

For more details on the iconic editor working see the visual editor.

> I'm thinking that control flow (other than perhaps a sequence) will not be available for this editor - but this is a deliberate decision of not to provide icon for the construct rather than fundamental limitation. I am also thinking that perhaps some values can be instantiated, such as simple text editing and numeric values. This is optional and should bridge more softly the gap between pre- and literate- children (often kids can write and read their names which they are likely to use in their creations before they can really read and write, and they understand small numbers)

> For our example, the children can now make sure the beaver does not die and wasps can be its friends. Instead a fox may appear that can kill the beaver, but the random moving wasps can sting the fox instead. For a more advanced uses, another tilemap can be provided for say parallax scrolling.

## Visual Editor

The visual editor is inspired by Scratch, Makecode, Blockly, Kodu and others where different shapes can be connected together and different shapes enforce legal composition. The visualized blocks can be navigated via the dpad and highlighted block/hole can be changed as decripbed in the _On Device Editing_ section.

As the visual level, kids should already be familiar with the when-do style of the iconic editor and will be introduced to actual programming concepts, such as expressions, control flow statements, variables, functions, etc.

The prefix nature of the language makes the editing and visualization straightforward. The visual editor uses simple chevron powerline-like visualization that saves screen real estate. Each statement starts and ends with the `|` character. If any expression part requires operands, it is followed by `>` as many times as there are operands. This is shown on the sequence below that creates a simple function call `foo.bar(4 + 5, 67)`:

    | ... |                               # Initial hole
    | foo > ... |                         # selected object foo, reqires action specification
    | foo > bar > ... > ... |             # selected action, we know it takes 2 arguments
    | foo > bar >> + > ... > ... |> ... | # added +, takes two arguments
    | foo > bar >> + > 4 > 5 |> ... |     # addition arguments added
    | foo > bar >> + > 4 > 5 |> 67 |      # whole expression done

Note the `>>` chevron above, which indicates nesting. While in most visual editors, nesting is done by graphically increasing the height of the statements so that nesting can be visualized, on RCKid's small screen, nesting is visualized by color change of the parts, which is indicated by the `>>` chevron which indicates color change. Note that this chevron does notreally exist and is only in the ASCII "art" representing the notation. Users will instead see a color change of the blocks. 

When the nested call is done, it can either be followed by another operand of the parent block, in which case we see `|>` at the end, where the pipe signals the end of the nested call, and the `>` sigals continuation of the parent call, and will be drawn in the parent call. Or it can be `||` where the nested *and* parent calls end at the same block. Note that a combination of those is possible, i.e. `|||>` which closes 3 expressions and continues the fourth one. The `||` can be rendered as a small bar block of the corresponding color. Examples below:

    | foo > bar >> + >> - > b > a |> c |> d ||
    # foo.bar(+ - b a c, d) in prefix
    # foo.bar((b - a)) + c, d) in infix

Visualized nesting happens when newly inserted element expects at least one argument, i.e. :

    | foo > bar > 5 |           # no nesting, 5 is literal value
    | foo > bar >> + > 5 > 6 ||   # nesting, + expects 2 operands
    | foo > bar >> foo > baz || # nesting (foo expects action specifier, baz expects no arguments)

An extension of the simple visual editor is the use of control flow. The simplest control flow statement is the sequential execution of multiple statements (code block). This is visualized by a small `||` narrow block to the left with `\/` joins (visualized in ASCIIart as the joins alone):

    \/ | log > print > "first" |          # first statement
    \/ | log > print > "second" |         # second statement
       | ... |                            # hole for the next, third statement, or empty

The `\/` short side block can also be selected and will offer control-flow specific actions such as adding before, after, removing, etc.

More complex control flow such as if statements or loops is visualized similarly:

    \/ | log > print > "pre-if" |            # log.print("pre-if");
    | if > == >> foo > bar >> 56 |           # if (foo.bar == 56) {
    || \/ | log > print > "its 56" |         #     log.print("its 56");
    ||    | ... |                            #     // hole for adding statements to true case
    | else |                                 # } else {
    |  \/ | log > print > "something else" | #     log.print("something else")
    |     | ... |                            #     // gole for adding statements to false case
    | end if |                               # }
       | ... |                               # // hole for after if statements

Further extensions to the visual editor can be introducing function definitions and perhaps even entire game object classes. Those will follow the same princples. 

It is important to note that the connection shape (always `>`) has nothing to do with types as opposed to the more conventional computer/tablet based block systems. Instead, types are used to limit the availability of options that can be selected from the input menus to ensure that a well-typed program will be produced when all `> ... ` hole types (i.e. holes in required positions) are filled in. To demonstrate, consider this example:

    | ... |       # first hole to add a statement
                  # this can be all available game objects (say log, device, player)
                  # all control flow statements (if, switch, loop, etc.)
                  # function definition and other global statements, etc.
    | log > ... | # we have selected log, but simply using game object in value position is not allowed here
                  # so action is required, where available options will be *all* actions of log
    | log > print > ... | # we have selected print, which takes 1 argument of type string
                          # so now *any* objects that have actions that produce string
                          # and any string creating functions will be available
                          # as well as string literals, variables that are strings, etc.
    | log > print >> device > ... || # we selected device, device is not string, must cal action
                                     # so now the options will only be device actions that return string
    | log > print >> device > id ||

The program in the visual editor is a collection of mapping between game object's events and their handlers, which form the actual source code. When events have arguments, pattern matching can be employed to only react to specific conditions, so for instance the following is possible:

    | device > onKeyDown > ButtonUp > : | ... | # where we react only to button up

> For the beaver game we can add a lot now, including for instance the ability of the beaver to hit back at its enemies with its powerful tail. Beaver can swim when in water and walk when on land. Instead of unique lives, we can have an HP gauge, etc. The movement of the wasps and foxes can be changed, so that foxes fear the wasps, etc.  

## Token Editor

The token editor works very similarly to the visual and iconic editors, with same hole editing principles. The difference here is that program code is entered as text in a token by token basis. So for instance the previous if example can be visualized as this:

    log.print("pre-if")
    if == foo.bar() 56
        log.print("its 56")
        ...
    else
        log.print("something else)
        ...
    ...

> Note that the `.` dot operator for membership has changed to infix now. I am not sure yet if that is a feature (leaning towards yes), but enough to say that there its infix-ness is not a problem as it is still mandatory in places where types would require it, you can think of the tokenizationof the above as `log` `.print` etc. The infix dot being part of the member selector. 

Thanks to the prefix notation and the DSL gramar used, this should look *very* similar to the visual representation already, just written purely as text and with operators & keywords that were missing from the visual description (such as the `.` operator, parentheses, etc.). 

Despite showing the actuall DSL code as text, the editing still happens at the hole insertion. When hole (`...`) is selected, the editor shows the available options that can be used to fill the hole, determined on the place of the hole both syntactically and type-wise, in the same manner it was used in the iconic and visual editors. 

Formatting will be dobe by the editor itself and the chevron style guides are no longer visible. But when selected, the call and its arguments can be highlighted in colors.

> This of course depends on the exact syntax, subject to be refined later. 

> For the beaver game, not that many new cool things can happen - the visual editor should already be turning complete. But the more complex the game mechanics get, the more useful the text editor can be by fitting more text on the screen and by utilizing more advanced language features (but those can in theory all exist also at the visual level). 

## Text Editor

This is the final tier that is identical to programming editors as we know them where the program code is entered character by character. Not expected to run on the device as the lack of qwerty keyboard makes character by character editing annoying. Yet the editor tier is pedagogically important because:

- it introduces the notion of invalid programs due to the free form editing, whereas the previous editing methods never allowed inserting invalid token in place.
- by the definition, can support the language in its entire complexity as full language simply means all productions and nonterminals are allowed.

> For the beaver, the only thig that changes is that very complex game interactions are possible now with more ease.

# Language Reference

I am thinking event based, simple syntax that will read nicely, infix syntax in pure text (but rendered as prefix in the visual & token editors). No curly braces because of off-side rule like Python. Dot operator for membership. Pattern matching. `:=` for assignment and `==` for comparison. Static typing with inference, algebraic data types.

> TODO to be done later

# Levels

The language itself can be viewed in *levels*, similarly to the Hedy and Racket, but more similarly to Hedy where the levels are more fine grained and introduce much more basic concepts, unlike the Racket's Beginner language which already does quite a lot. 

Furthermore, certain levels can only be expressed in particular editors. It still holds that any higher-level editor can express everything te editor below it can, but only the text editor at the very end is required to be complete. 

> But I hope the token-based editor can be complete, or near complete too. At the moment I am thinking the visual editor should eventually support everything up to creating functions and extending existing game objects, while maybe creating completely new game objects can be omitted. The iconic editor on the other hand will be rather restrictied, only show things for which icons will be defined and will likely lack control flow (maybe sequence ok) and variables (maybe passing them ok).

The below is not in any particular order, just ideas for features that can define levels:

- assets only (no code editing only static data)
- game objects and their events & actions, explicit values
- types, complex constructors (such as point, etc.)
- variables
- sequential execution
- conditional statements
- loops
- writing own functions
- extending game objects with events and actions
- writing own game objects
- memory management
- collections

> TODO to be done later, can get inspire dby hedy & racket stuff

# History

Language has switched to prefix notation to simplify the editing paradigm. The `<` chevron is no longer used to show that an expression returns value - this is not needed as the type based selectors will only show valid options anyways.

In the olden days I was assuming full C++ SDK as the latest level of the mastery ladder. I have abandoned this as the full C++ SDK is arguably a diffrent programming language and experience at *all* (flashing, really complex memory management, hardware interaction, etc.).

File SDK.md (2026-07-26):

# RCKid SDK Design

> This is the software design of RCKid part and presents the generic part of the SDK. See [HARDWARE.md](HARDWARE.md) for details about the hardware architecture and readme files in the respective app folders for their details.

RCKid sits between a complex device running an operating system and single app cartridge systems of the gaming handhelds of the past. While there is no OS and multitasking is not supported (with a few notable exceptions below), the SDK does provide many of the features traditionally associated with operating systems and desktop environments, albeit at a very limited scope, hence this document.  

## Backends

The SDK supports multiple backends - hardware or virtual architectures on which the cartridges running the SDK can be executed. The backend abstracts away the particular hardware details so that no code changes, only recompilation of the cartridge is necessary. 

The currently supported backends are:

- fantasy
- mk3 

## SD Card Contents

The SDK expects for most of its functionality to have an SD card attached in the device. The SD card contains most of the user data, media files, etc. The following format of the SD card is expected:

    \
    |-- contacts.json
    |-- settings.json
    |-- apps
    |     |-- apps by names and their contents
    |     ...
    |
    |-- files
    |     |-- icons
    |     |-- images
    |     |-- music
    |     |-- recording
    |     ...
    |
    |-- games
    |     |-- gamefiles for emulators
    ...

### Application Folders

Each application has its own folder under the `apps` root folder. The folder has the following structure:

    AppName
       |-- data
       |-- resources
       |-- saves

The `data` folder is the app home and is completely in the application's control. The SDK does not understand what it is, nor does it  

## Resources Used

- `pio0` for display and sd card (high pin bank)
- `pio1` for audio (low pin bank, including cartridge pins)

## Simplification Ideas

The SDK only works with apps and tasks. The app is the only thing that has access to screen and it must periodically call tick() method every frame or roughly 60 times per second. The tasks on the other hand specify onTick() method, which will be called by the SDK during the tick itself. 

- have two kinds of taks - heavy and light tasks. Light tasks can run always, while heavy tasks will be killed when standalone mode requested by the app

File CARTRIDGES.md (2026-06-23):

# Oscilloscope & Function Generator

> Uses the two ADC pins for 2 channel oscilloscope and some resistor ladder or PWM for custom function generator. Should work with 0..24V.

# Multimeter

> Ideally simple multimeter with GND, V, A jacks that can measure voltage, current and resistance. Maybe also add somehow an option that can measure *voltage* and *current* at the same time.

# Digital Analyzer

> A cartridge that can be used for various digital functions. Should support a simple logic analyzer (at least 4 bits), should also be able to communicate explicitly with devices via UART, SPI, I2C, etc. Should be able to pass through the UARTs into CDC USB device. The inputs would be 5V tolerant, but output will be 3v3.

# RCKid Development Cartridge

> A special cartridge that will have extra PCB on it that would allow it to connect to the debug port on another rckid. It could then be used as UPDI programmer, serial reader for the AVR and RP2350 (or passthrough for USB) and SWD debugger via USB. The connector can be on cable and we can have this as a simple GPIO out cartridge and special board with the updi stuff on it. 

# WiFi & BT

> Uses RM2 from Raspberry Pi for BT & WiFi access. 

# Radio Cartridge

> The below is comments from version 3.1 which had the Si4705 chip onboard. This was later changed and radio can move to its own cartridge if needed. 

[Si4705](datasheets/si4705.pdf) is the chip used. It is FM only receiver with ability to use both embedded and headphone integrated antenna. The FM chip also comes with [antenna guidelines](datasheets/si4705-antenna.pdf) which contains layout and typical application information. It communicated withj RP2350 via I2C and has two extra lanes - RESET and INT. We leave GPO1 unconnected so that I2C communication mode will always be selected. Finally there is the [programming manual](datasheets/si4705-programming.pdf) for the I2C setup.

I've also found an [Si4705 module](https://media.elv.com/file/140984_fm_rm1_schaltplan.pdf) whose schematic can be of use. 

The rest of the pins are used as follows:

- `FMI` is connected to headphones antenna
- `RFGND` goes to ground
- `LPI` is the embedded antenna
- `RSTB` is the RADIO_RESET to RP2350
- `SENB` goes to ground (I2C address selection - `0b0010001`)
- `SCLK` and `SDIO` are the I2C SCL and SDA lines to RP2350 respectively
- `RCLK` and `GPO3` are connected to 32.768kHz crystal
- `VD` and `VA` both go to `IOVDD`. VD has 100nF capacitor and VA has 22nF capacitor (from the app in antenna datasheet)
- `GND` is ground
- `ROUT` and `LOUT` are analog outputs. They go to the audio codec via 10k to ground and 100nF capacitor
- `DOUT`, `DFS` and `DCLK/GPO3` are not used and left floating (digital audio out)
- `GPO2` is connected to the RADIO_INT and goes to RP2350, pull-up does not seem to be necessary
- `GPO1` is not used

### Headset Antenna

The headset antenna is described in the antenna datasheet, page 19. Headset ground is connected to gnd via 270nH inductor as per the datasheet and to the FMI pin via a 100pF capacitor. To insulate the ground antenna, ferrite beads are installed on both left and right audio outputs, as well as the headphone detection line. 

### Embedded antenna

As per the antenna application note, page 31, the embedded antenna is connected directly to the LPI pin win 120nH inductor to the ground. The inductor is 0805 so that it's hand-solderable. The ESD protection and current limiting resistor are not necessary as there is no exposed connector to the embedded antenna. 

### External Crystal

We are using the same crystal as AtTiny3217. The load capacitance is 12.5 pF, which is roughly in the middle of the rangle per datasheet. While the dev-board had 22pF capacitors, the crystal looked like it is not swinging fully, so we are trying 15pF for the device, which would correspond to 5pF stray capacitance. This is under the assumption that lower than ideal capacitance is better than higher than ideal, but needs to be verified. Internet says this should not degrade the crystal accuracy too much as only a few seconds per week max.

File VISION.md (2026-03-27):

# RCKid's Story

> I want a handheld game console targeted at kids that will be all about creation, not consumption. Something that will be their first personal digital device. Like a phone, but simpler, safer, and hackable. A device that would grow with them, both in software where they would be able to progress to more and more complex forms of creativity with it, and in hardware extensibility.

## How I Got There

On Christmas 2021 I finished building an mp3 player for my kids. I really enjoyed the work, and seeing my kids using the player gave something like a "meaning" to my life. But I was also left with lots of spare parts - screens, MCUs, speakers, microphones. To make use of these, I jumped into my next project: taking some old LEGO technic motors and creating a **R**emote **C**ontroller for **kid**s from the spare parts. But feature creep hit hard. With a dpad, MCU and radio, I could add a spare screen - kids love displays. Now I had a display, MCU and dpad - enough to play some simple games. Kids love sound, so let's add a speaker. If only I could add a microphone, I could make it a walkie talkie too, but there was no free pin left. Upgrade to bigger MCU, problem solved. Bigger CPU can drive a better display - kids love colors! Writing games for a color display would be hard without drawing skills, but I could use emulators and play old games! Kids love old games! But the MCU wasn't powerful enough. Well, swap it for an even beefier one - RPi Zero!

But programming for RPi Zero was no fun for me as a programmer. And when I built the device, I realized I didn't want to give it to my kids. It played lots of old games, music, movies. But it was all about consumption. So I scrapped the project and started fresh.

Out of this came the current version of RCKid (RC still stands for Remote Controller - too late to change the name :). It is small enough to fit in children's pockets, polished enough to look like a real product rather than a DIY hack or an obvious STEM educational tool. Powerful enough to be genuinely useful, but designed with creation first and foremost.

## Current Status

Let's be honest. This is an enormous undertaking and at this point I am working on it only in my free - mostly night - time. I have third generation prototypes that my two kids use pretty much daily. The device has a GB emulator so that games created in GB Studio can be played, an mp3 player, Telegram messenger (with WiFi cartridge), flashlight, TV remote, alarm clock, contacts and a bunch of other utility apps. I also have a simple asset editor for icons.

I used the self-imposed Christmas deadline and Baby Jesus' logistical services (he delivers presents with a bit of magic where I live) to deliver units to my two beta testers - and their cousin. That's not many data points, but:

- Both my kids take it with them everywhere and genuinely treat it as their personal device - with visual customizations, think early cellphone themes
- My 5 year old regularly uses the humble icon editor to create what he calls maps of houses - living rooms, towers, cellars, you name it
- My 8 year old is hooked on the games, wants to create her own (started learning Scratch to that end), and because reading is required, her reading skills have improved significantly thanks to the device

## Growing With the Kids

My vision for the future is far greater than this. I would not shy from calling it megalomaniac. But the fact that I have persisted with this for so long already gives me some hope that I can deliver on this big picture as well.
My plan is to evolve RCKid into an educational platform for kids and teens. There are plenty of such devices already, but RCKid is unique because:

Wait for it... It has cartridges! 

Cartridges add tangibility to creations. When you create a game in Scratch you save it on your parents' computer somewhere. When you create a game for RCKid, you save it on your cartridge - one you can give to a friend to play. The cartridge system also allows nearly endless hardware customization. I already have plain, WiFi and NRF24L01P cartridges, with LoRa, camera and FM radio planned.

I also plan a ladder of creative tools that kids across a wide age range can use (details in [Development Ladder](LADDER.md)):

- Small kids without any literacy can start with asset editing - tilesets, tilemaps, sprites, sounds, music trackers - that will allow them to customize existing games. This teaches decomposition and basic game concepts without requiring reading or writing.
- A visual editor where behavior, not just appearance, can be tweaked without literacy. This teaches decomposition of behavior into sub-actions in time.
- A block editor (like Scratch), which adds more agency, teaching control flow, modularity and so on.
- A language editor with a DSL that teaches describing algorithms textually and correctly.
- A C++ editor, which teaches more advanced concepts.
- And finally, a full C++ SDK that gives complete control over the device.

I think this is big. A 5 year old who cannot read or write can create games that feel genuinely their own. And since every step above is a superset of the previous one, the games they create will grow with them for years to come, becoming more uniquely theirs with every new skill they learn.

## Personal Ownership Matters

I built a device for consumption and then realized as a parent I didn't want that for my kids - so I rebuilt it for creation. As an educator I started thinking about how to nurture that creative instinct systematically, which led to the progression ladder and the personal ownership model:

RCKid is intended to be *personal* device -  in fact it will likely be the *first* personal digital device for the youngest kids. It is not supposed to be a kit they leave at school after the lessons are over. It should be *theirs* to take home. That way the personal ownership blurs the line between school and home. This increases participation, which leads to creating and learning: Kids can spend their free time improving their projects and then impressing their friends with their creations - and because cartridges are physical and shareable, they can give their games to their friends who will run them on their devices. There is nothing more rewarding than seeing *your* creation being used by somebody else.  

That is why I have designed RCKid to look as polished and product-like as I can and why I put emphasis on the device being generally useable - not just narrowly focused STEM educational kit. But none of the diy hackability is lost - it is literally a cartridge swap away!

But the story does not end here. I have realized that personal ownership matters most to the kids who have the least. A child with hundreds of toys gets one more device. A child with few possessions takes RCKid seriously in a way that makes the whole mission work better. The kids who need it most are also the kids for whom the personal ownership model is most powerful.

This is why one of RCKid's long term goals is to ensure that cost is never a barrier. A device given freely to a child who has little is not just a gift of a toy - if the premise works, it is a gift of a better future through learning. Validating that premise carefully and honestly, starting with what works and building toward who needs it most, is the real mission.

## Future Plans

I would like to finish the fundamentals - a solid SDK that allows painless creation of all sorts of apps, so that the device feels truly useful and coherent. I still need to iron out some hardware details (working microphone, DFM improvements). Then I want to validate the creation angle more concretely: implement asset editors, a simple visual editor, and basic game templates for the youngest target audience.

Two beta testers are better than zero, but I would like more. A small pilot in a local school - ideally with kids aged 7-9, where the progression from asset editing toward behavior customization can be observed naturally within a single school year - is the next concrete step. Starting with motivated kids in a supported environment, learning what works, and then taking those lessons toward the kids who need it most.

I hope to make this under the self-imposed deadline of my two beta testers growing out of the target group eventually:)

## What about AI?

We live in times when you might wonder why bother teaching kids STEM when most programming might soon be done by LLMs. But you do not teach 6 year olds how to program — you teach them the art of algorithm description. Most kids who will have RCKid will not become programmers. This was true before LLMs and remains true after. The whole point of STEM education is to teach universally useful thinking skills in ways that do not require deep technical knowledge. Decomposition, sequencing, abstraction — these are cognitive skills that predate programming and will outlast any specific technology.

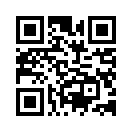
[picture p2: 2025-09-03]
hardware/images/url_qr.png

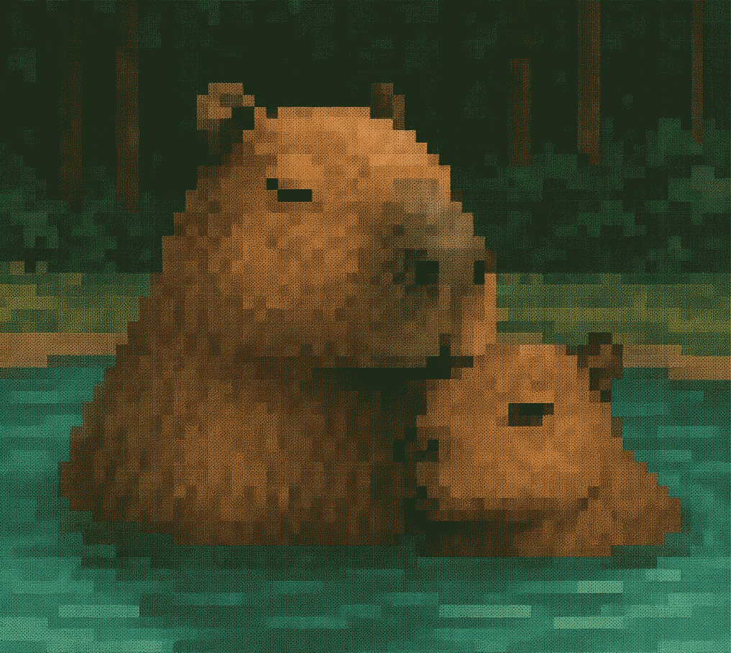
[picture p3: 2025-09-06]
hardware/images/silkscreen-cartridge-capy.png

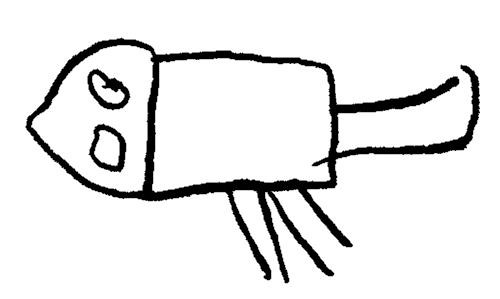
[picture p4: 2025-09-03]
hardware/images/beaver.png

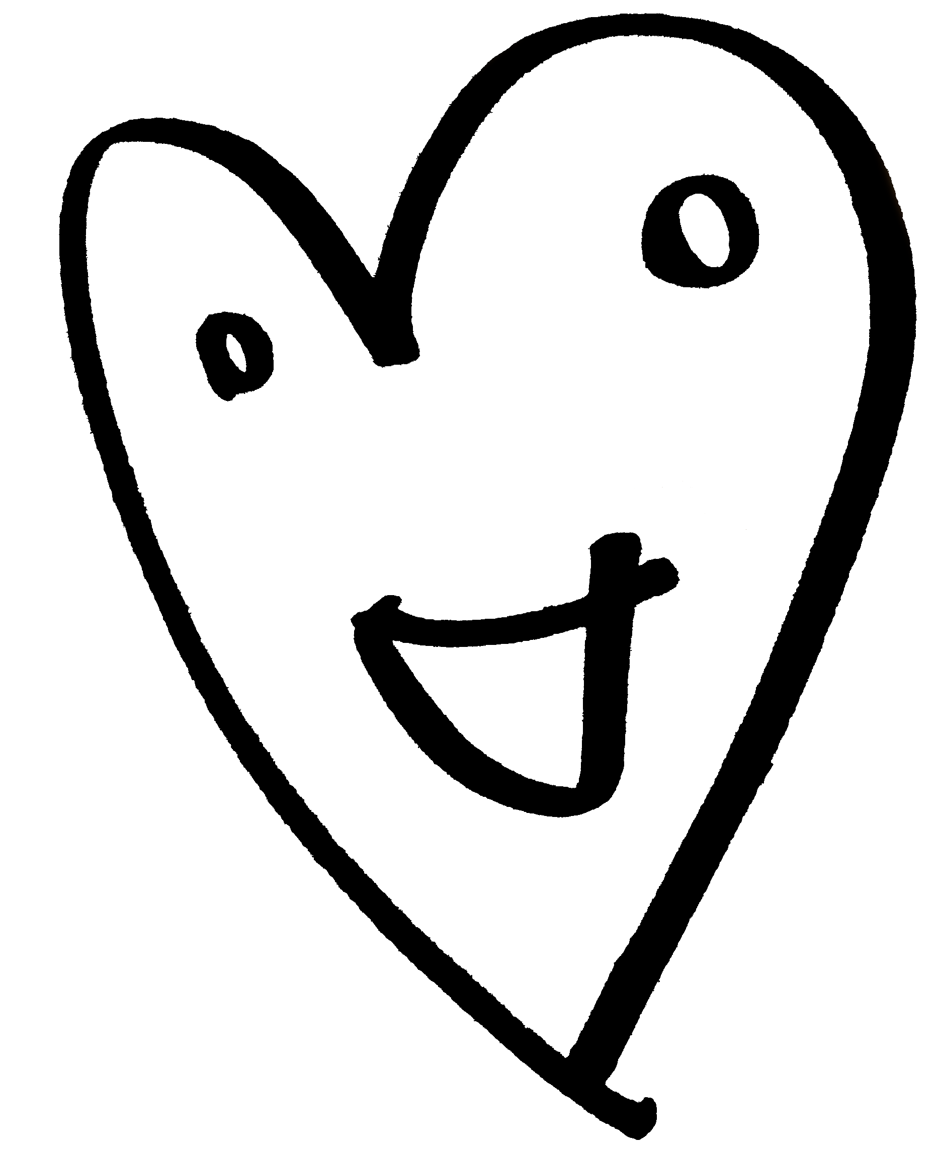
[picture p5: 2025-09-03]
hardware/images/heart.png

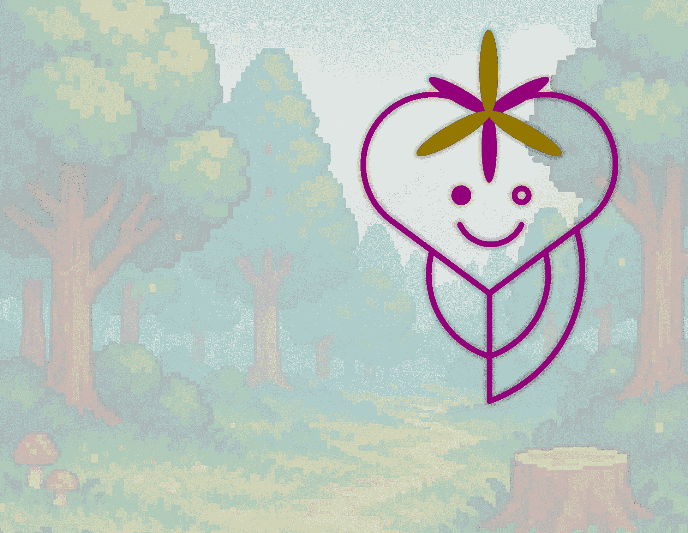
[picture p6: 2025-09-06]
hardware/images/backplate.png

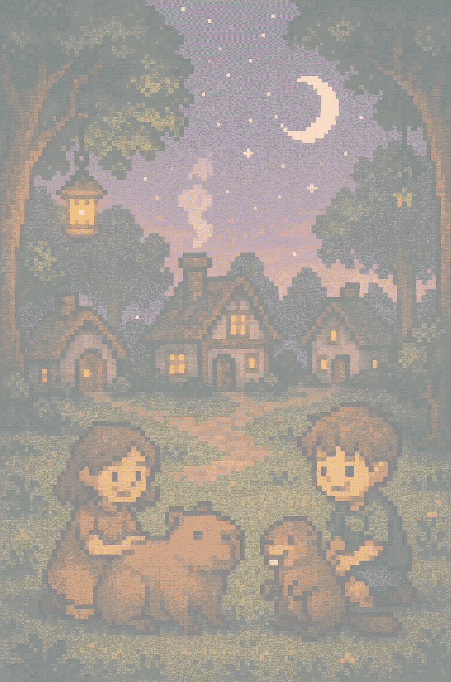
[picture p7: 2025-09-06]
hardware/images/silkscreen-front.png

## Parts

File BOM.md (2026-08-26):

# Bill of Materials

Most of the electronic BOM is done by ordering assembled boards (currently from JLCPCB), and as such are not listed here. Refer to the hardware folder for the pcb project. The following are extra items that need to be purchased:

- [1x display, 320x240 IPS FPC 40pin, no touch](https://www.aliexpress.com/item/1005004629215040.html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) - this is the FPC connector version for easier soldering. The device itself uses 16bit parallel mode. 
- [1x battery](https://www.aliexpress.com/item/1005007102975858.html), this one is only 1200mAh, but comes with JST-PH2 connector and cable length that makes it easy to put in. Alternatively [tme.eu](https://www.tme.eu/cz/details/accu-lp503759_cl/akumulatory/cellevia-batteries/l503759/) as 1350 mAh 503759 with different connector that will need adapting
- [1x rumbler](), spring contacts
- [1x speaker](https://cz.mouser.com/ProductDetail/Same-Sky/CMS-160903-18S-X8), spring connectors to the main pcb
- [6x screws](https://www.nerezka.cz/sroub-m-2-x-4-din-965tx-a2), M2x10
- [6x screw inserts](https://www.tme.eu/cz/en/details/b2_bn1054/threaded-insertions/bossard/1386727/) that are compatible with plastics used for the top plate. 

- [battery connector]()
- [headphones connector, sinking](https://cz.mouser.com/ProductDetail/490-SJ-43504-SMT-TR)

Things below are not needed for v3.2 but might return:

- [3x buttons](https://cz.mouser.com/ProductDetail/Omron-Electronics/B3U-3000P-B?qs=AO7BQMcsEu4JAdtnbsGArA%3D%3D), hand soldered for home button and volume up & down
- [6x screw inserts](https://www.prusa3d.com/product/threaded-inserts-m2-short-100-pcs/) if the top plate is made of thermoplastics, such as pla.

## Cartridges

- [1x flash memory]()
- [1x 10K resistor]()
- [1x 100nF capacitor]()

Optional cartridge extras

- [Flashlight LED](https://www.tme.eu/cz/details/l128-4080ca3500001/vykonove-diody-led-emiter/lumileds/)
- [LED Driver](https://www.tme.eu/cz/details/ap2502ktr-g1/stabilizator-napeti-obvody-dc-dc/diodes-incorporated/) or from [mouser](https://cz.mouser.com/ProductDetail/Diodes-Incorporated/AP2502KTR-G1)
- [IR LED](https://www.tme.eu/cz/details/ir204c_h16_l10/infracervene-diody-led/everlight/)

## BOM Optimization

Current BOM for 100 units is at around 2000 USD, with the following biggest offenders:

- ATTiny3217 is even more expensive than RP2350. The idea is that it can be replaced with some of the cheap Puya or similar MCUs (such as https://jlcpcb.com/partdetail/PUYA-PY32F002BF15U6TR/C7469099, or https://jlcpcb.com/partdetail/PUYA-PY32F030K28U6TR/C3018718). We need simple ADC, neopixel control, PWM for the display & rumbler, UART for debug and I2C for RP2350 communication. Those should be easy to have, the biggest task is likely the external and kinda precise RTC.
- LSM6DSV is pretty expensive and offers really nice pedometer. We can ditch the pedometer feature, or we can make the IO MCU provide a cheap pedometer filter for the ACC itself. Especially with the larger chips this can be possible.
- LTR390UV is another expensive sensor. Can be replaced with simple LED that can be status & light sensing (thanks to Paul Dietz's hack). Not enough pins for it in ATTiny3217, but might be enough on the Puya chips
- the HW switch for analog cartridge to the audio codec is also pretty expensive. Does not have to be populated though
- 220uF capacitors are expensive. Need to check if we can drop them to 100uF which gets a lot cheaper
- side buttons are also pretty expensive and I want to replace them anyways

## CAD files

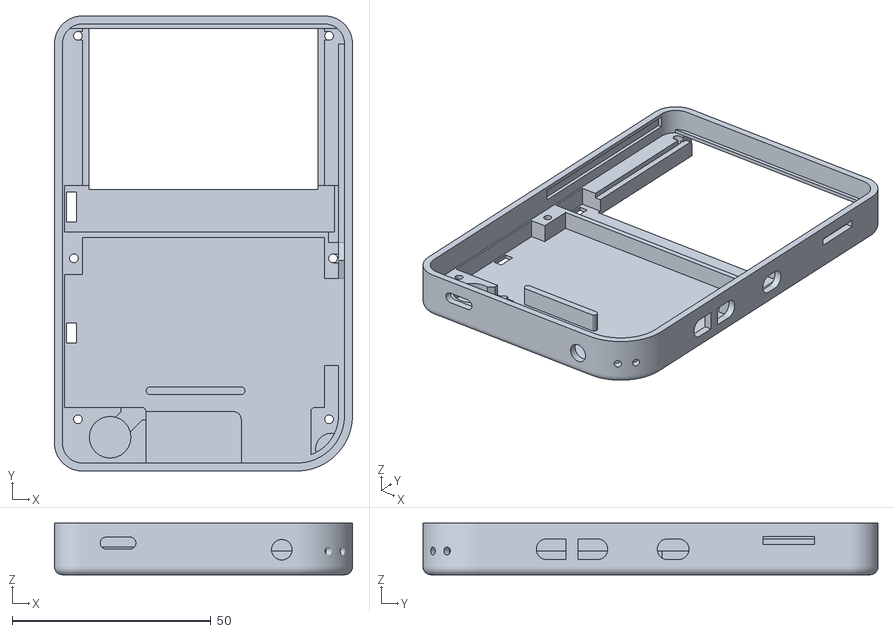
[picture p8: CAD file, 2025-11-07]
hardware/case bottom.stl
75.0 x 114.5 x 13.0

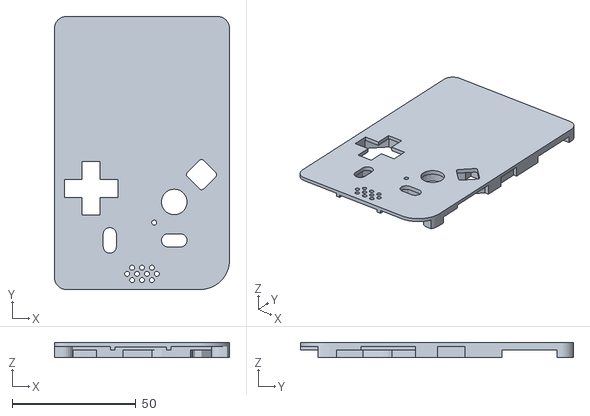
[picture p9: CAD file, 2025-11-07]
hardware/top fused.stl
70.6 x 110.1 x 6.00

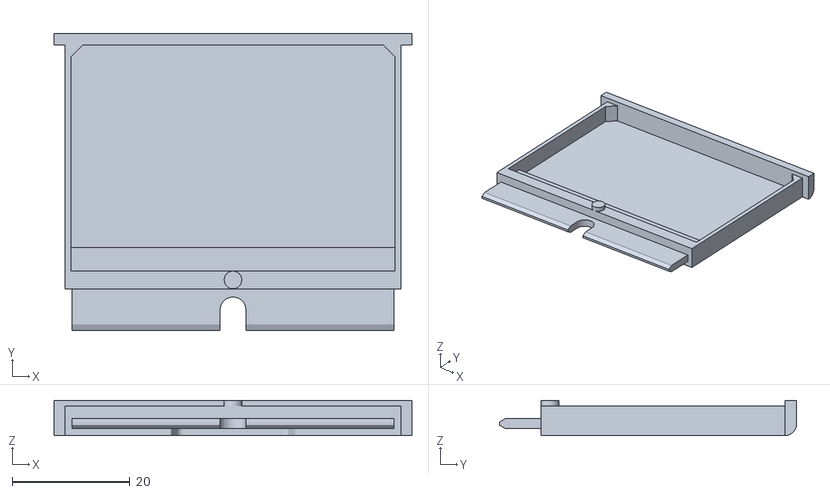
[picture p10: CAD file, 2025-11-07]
hardware/cartridge fused.stl
60.7 x 50.4 x 6.00

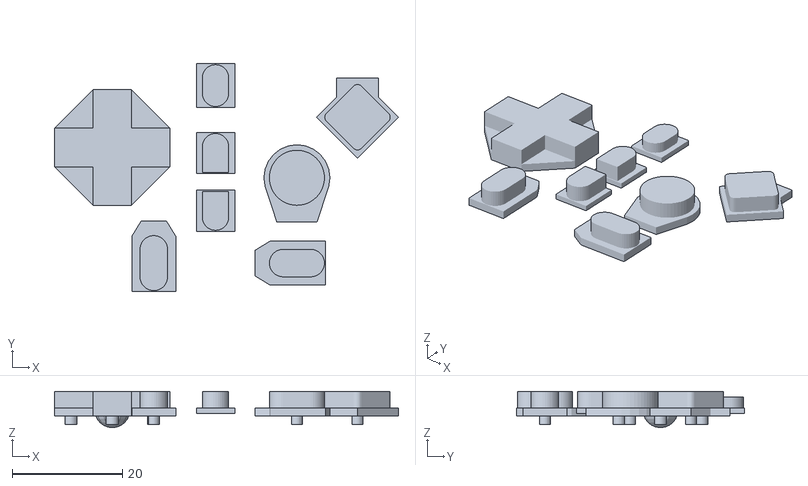
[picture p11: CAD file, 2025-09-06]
hardware/buttons.stl
62.5 x 41.4 x 6.60

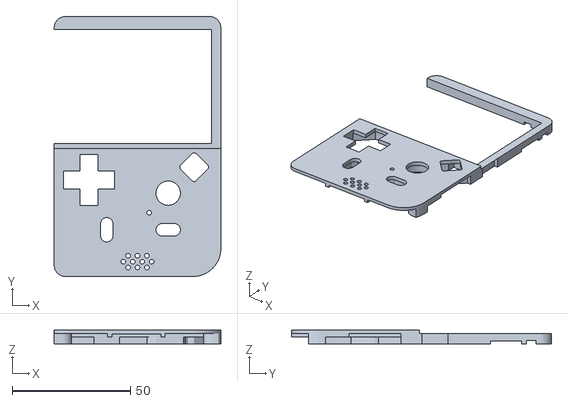
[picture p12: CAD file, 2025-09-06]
hardware/top for display cover.stl
70.6 x 110.1 x 6.00

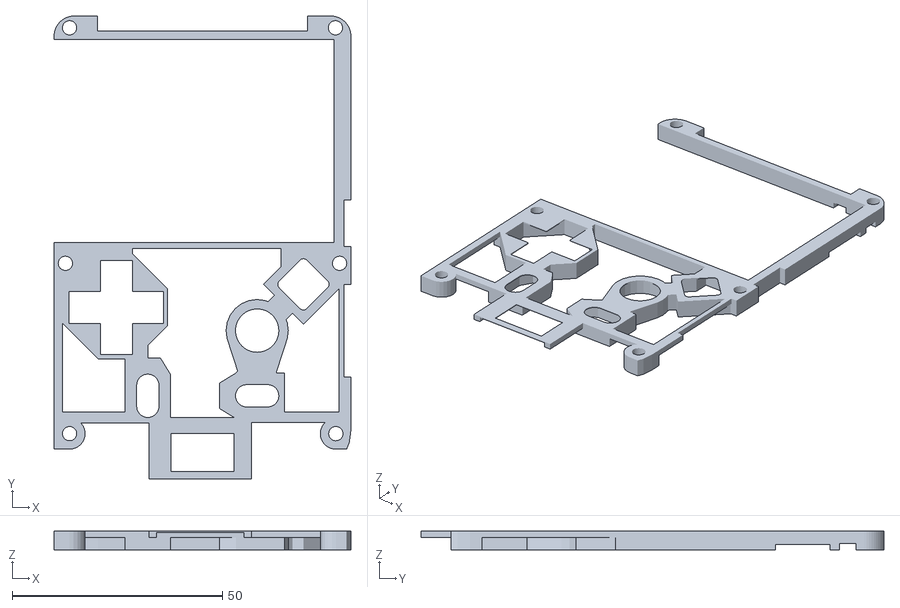
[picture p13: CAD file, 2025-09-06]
hardware/top.stl
70.6 x 110.1 x 4.50

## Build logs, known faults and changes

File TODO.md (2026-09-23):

# Checklist

- looks like LCSC is offering very reasonable acrylic front panels with cutouts, would cost around 1 USD per unit in 100 batch, which is a lot cheaper than the transparent 3d printed case (!!!)
- there seem to be 3v3 neopixels - this could be useful for rckid proper as well (now tested in lego remote)
- volume down not centered properly
- maybe enlarge the top plate a bit to fit properly in the slightly large nylon bottom. Or shrink the nylon?
- uart is wrong because the pins available on cartridge are only uart0, which is already used by the serial out. Can be fixed by making RP_TX pin 8 (instead of SD_CD), which is UART1
- audio codec GPIO1 should have test point
- verify GPIO1 is tied to ground when not used, or set output to GND
- headphone jack soldered by JLCPCB? 

# General SDK

- implement the left-right animation style for widgets

- no check of the LauncherMenu type so we get overlay even when none should be there (segfaults)

- support changing app name via the overlay mechanism (maybe?)

- add extra settings item (identity, personalization, etc.)

- add icons for the rgb effects (decorators)

- add wave (breathe) keyboard effect for rgb, this has to be timed well on ral device
- does the start then drop immediately effect for keyboard press work? 

- verify if the brightness in rckid.h/rckid.cpp is 0..15 or more and have the 0..255 be done at the HAL level

- default palette can be system wide

- add telemetry (will be useful for the pilots, record time & app start, or end)

- improve value parsing in Reader (bool, ints, etc.)
- how to do heartbeat? (static initializers?)

- for game saves use different bookmark icon (red maybe?)

- make UNREACHABLE & friends part of platform? This should make it write between mkIII, fantasy and ATTiny stuff

- canvas app can be rendered in single call technically

- deal with wakeup interrupts

- budget reset & the whole wakeup business

- add extra tiles for all volume levels

- should ini reader and writer own the stream? Might simplify things a bit in the API

- when clearing drawing buffers with bg color, this is very inefficient and can be done with DMA right after screen is updated

- waiting for display update done could make the cpu sleep

# Apps

Wakeups
- alarm clock
- steps daily reset
- piggy bank daily allowance top up check

Basic util apps:
- level

Games (port from mkII)
- sound in tetris
- sokoban
- space invaders
- pong
- sliding puzzle

## GBCEmu

- RTC is not implemented and will not read values well, nor can it write them
- tearing is kinda ugly, can be fixed by framebuffer, will cost around 23k, but then scaling & rendering can be done by other core
- extra settings (colors, etc. for system & gbcemu)
- improve audio fidelity for GBCEmu
- figure out how debug mode for gbcemu should work now

# Programming & Editors & Ladder

The plan is to start with a simple game - cat chase - there is a mouse and a cat, mouse moves randomly, cat chases it, controlled by the player. The aim is to program this game at the C++ level to bring all the pieces together and make sure the c++ code looks decent and easy. Once I have this I can start writing the dynamic wrapper for the layers below (blocks & visual) and asset editors. 

So what I need:
- spriteset asset
- sound asset
- sprite object
- sound object
- basic game loop & input, collisions

- very basic descriptors might be working, the code needs commenting, testing.
- descriptor/game object infrastructure for matching arguments of events should be added 

# Backend - MK3

- tick updates for display do not seem to be working every second
- audio plays only in R

- sws-tx is really uart PIO, rename as such and we can use it for TX output even on current HW version which means the cartridge available UART can be used 

- determine SD speed and how fast can I go? -- do this only for the newer version with different protection

- implement light detection capability for mk3

- how to detect we are done playing music? in the DMA

- avr firmware wakeup timing

- heapend on mk3 should return current sp or something like that to verify that we are not growing over

- add support for overclocking, and in the missing adjustment for display pio in the hal layer:

        static void adjustSpeed() {
            pio_sm_set_clock_speed(RCKID_ST7789_PIO, sm_, RCKID_ST7789_SPEED * 4); // 2 cycles per pixel
        }

# Backend - Fantasy

# Hardware

- headphone detect does not seem to be working (revert to GND second ring testing)

# Hardware - Features

### JACDAC

- verify we send *everything* in JACDAC (wait for DMA and stall)

### USB Link Cable

- direct connection to other device
- via usb cable/wifi/nrf or other means, when activated user can select which link implementation to use if multiple are possible so that the API is the same and does not care with implementation
- the USB can also be used as serial output 

----------------------------------------------------------------------------------------------------------

# Immediate Roadmap

- this might be better button: https://jlcpcb.com/partdetail/ALPSALPINE-SKRABCE010/C19724057
- figure out the side buttons if there are ones that can be soldered by jlcpcb and be better centered
- this might be better speaker: https://cz.mouser.com/ProductDetail/Same-Sky/CMS-160903-18S-X8

# MK3 HW

- this could be better side button (cheaper too): https://jlcpcb.com/partdetail/XKBConnection-TS_1010_CA/C692458
- home button thickness tested at 1.3mm

# DevBoard Checklist

> X means done, - means cannot be done

- [ ] check SD card insertion detection
- [ ] draw LoRA cartridge
- [ ] add board for debug connectors

# MkIII Checklist

Nice extras would include:

- [ ] timer app
- [ ] port more games (15 puzzle at least)
- [ ] add high scores

Must-have before wider release

- [ ] AVR bootloader so that AVR firmware can be updated too
- [X] telegram messenger
-   [X] notification
-   [X] preserve unread notification across runs
-   [X] show unread message icon with chat menu
-   [X] delete chats
-   [X] chat names & icons 
-   [X] add contacts
-   [ ] run in background
-   [X] add telegram ids to users
- [ ] webpage, releases, updates, etc.

Polish
- [ ] RGB dimming that preserves colors (? is possible)
- [ ] in header, show volume value, not just bar when changing (?)
- [ ] some way app can show which buttons it reacts to (faint glow for key press, only use the effect on valid keys otherwise)
- [X] accelerometer controller background & background selection

# TODO

- turn brightness *on* in avr forever and then try it looks like only problem when not DC connected
- and only every second turn on is a problem

- likely there is an issue with timing & drawing of the lines on GBCemu we have VBLANK first then start drawing line, also songbird does not work well during transitions...

- or maybe add circular scrolling to labels?
- make label scrolling nicer to configure so that inside audio player when refresh rate is 1s we can still do nice things, or can we increase refresh rate? 

- make level app draw circle and look prettier, maybe draw angles even

- rumblerOff does not actually turn the rumbler off

- drawing preserves state like games
- allow messages to send images

- keep the offset so that we can go back (in messages)
- check wifi available, etc. 
- Friends::ContactViewer should be own dialog, not part of friends ideally

- add airplane mode & sleep function (also uncomment the options in home menu)

- callback to wifi status
- https://github.com/raspberrypi/pico-examples/blob/master/pico_w/wifi/http_client/example_http_client_util.c

- allow messages to save to existing contact as opposed to always a new one

- add confirmation dialog to many deletions
- why popup menu takes pointer and not a reference? 

- update & processEvents are not really honoured in the ui 

- scrollview scrolling when focused
- update scrollview to be able to scroll horizontally as well, check its update method for scrolling handling, cleanup the code

- for the flashlight, somehow at the beginning there is a faint glow even when turned off, this seems to disappear after a while

- for rumbler in AVR, ignore the values that are below some threshold that is observable on mk3
- allow breathing to start at specified offset in the animation

- clean-up the code around display initialization

- the color settings should be stored, perhaps per game?  (gameboy)
- and when colors are updated, different colors should be update-able at the same time

- some avr commands are longer than 16 bytes, which means it cannot be stored via the I2C async commands

- when stack protection fails, it will fail in the error code as well forever, update stack on device, do new thread on rckid? 

- fix/check device fatal error & stack protection

- add events for getting icon for files & on file selected for file browser
- add actions for file browser such as rename, copy, mkdir, etc.  

## HW

- https://jlcpcb.com/partdetail/JST-S2B_PH_KL_LF_SN/C160237 (use this for battery connector)
- JST-PH2 batteries from https://www.aliexpress.com/item/1005007102975858.html
- make the cartridge pcb 1.6mm standard thickness? Basically it would only simplify the jacdac stuff, otherwise unnecessary

- is there a way how to make the headphones work with headphones that have microphone as well? maybe by connecting tip with some large resistor to 0 (68k or so) and then connecting the tip mate via even higher resistor to VCC as a pull up. Then it will read close to 0 when not inserted and VCC when inserted. But will this upset the audio? It actually might work and I can ignore the second sleeve and it would work with all headphones! (can I make it work with current audio setup by rewiring?)
- might get super pretty front panels from here: https://www.hopesens-glass.com/
- need to re-route NRF and loRa boards (pull-up for IR control at least, schematics is correct)

## UI

- proper palette rendering, do offsets
- palettes in the UI stuff (header & dialogs)
- when updating multiple attributes of a widget the recalculate after each one of them is not necessary
- also maybe change the resize to change and make it general method for ui change stuff
- review dialogs & how they are configured and used (custom title, context menu for file dialog, etc.)
- isBorder from drawing editors & palette should be part of some common widget (same as border drawing) 

## Audio

- add square and white noise waveforms

## Graphics

- should colorRGB be 3 bytes? Or should it be true to the 565 representation? 
- visit loadImage to determine if the setAt is good enough (conversition from int16 to Color to int16 seems inefficient)
- image can have pixel arrays form ROM as well - just ensure on the fantasy that we are not deleting the memory if it comes form "ROM" - sth like lazybitmap? 

- optimize surface functions for common cases
- add specialization for 16 bpp bitmap renderColumn that simply does memcopy

# PCB

> MK III ideas
- can use DMA & control blocks to do the 256 palette lookup with FB w/o involving the CPU
- when using NiMH batteries, due to very flat discharge curve, the battery voltage reading might not be really useful

> After XMAS, but can be done with RP2040:

- the SD card initialization routine does not work for SDHC cards, only for SDXC (not a blocker for xmas)

- hall of fame and others can be apps of their own that just reuse the canvas from previous run, but delegate the controls? How though

- maybe not use joystick, but keep it as an extra file so that each app can configure it properly, including things like position. But how to integrate with settings? 

- maybe even RGBA colors? 
- rumbler & LED effect done event

- recording in fantasy

- libopus decoder & encoder library
- jpeg decoding library

# Power Measurements

> Those are from mk2, keepin them for reference, should verify with mkIII

- 50% brightness, radio on 80mA @ 5V
- speaker at default volume 100mA @ 5V
- with extra power, we get at 120mA @5V
- headphones are small, ~82mA

- actually here: https://www.aliexpress.com/item/1005001515210980.html
- silicone rubber dome to test: https://www.aliexpress.com/item/1005008583229786.html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

## Memory Management

Then I have images, bitmaps, canvases and ImageSources. 

ImageSource is a class that can be used to identify an image. This can be done via (a) path to a file, or (b) memory buffer that contains the image data itself. Both files and memory buffers can be in different formats, namely:

QOI, PNG, JPG, Raw. 

Raw is interesting especially with the immutable_ptr. It is a format that first has the raw data as they would be unpacked, and this is followed by width & height. This allows no allocation for images stored in flash in the raw format. At the moment the raw format only uses RGB565 color representation. I am proposing to add third - last byte specifies the bpp/format and it can be RGB565, or indices (256, 16). Makes sense? 

Finally I have canvas. Canvas at the moment only supports RGB565, but I am thinking maybe it should support multiple formats too.

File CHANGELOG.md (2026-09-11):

# Hardware Changelog

This file contains brief descriptions of all the manufactured versions of RCKid mk II. In between versions were designed, but not actually manufactured and are not shown here.

## Curious Capybara (mkIII v 4.0) - planned

Further BOM simplification with a major overhaul of the IO system:

- ATTiny3217 replaced with Puya PY32F030, which is a lot cheaper
- accelerometer replaced with a cheaper non-pedometer version
- light sensor replaced with LED for both sense and emit
- neopixels switched to 3v3 variant, which elliminates the 5V charge pump and level shifter
- cartridge 3v3 rail replaced with high side switch
- side buttons replaced
- expensive 220uF caps replaced with 2x 100uF
- further minor BOM simplifications
- ESD on cartridge pins

## Beaver King (MkIII v 3.2) - July 2026

Aimed at assembly & BOM simplification. Incorporates changes in SDK 1.0 from version 3.1 (no AVR_IRQ pin, etc.). Things that are to be validated by this version are:

- taller front buttons with integrated stems for better tactile feel and simpler button construction
- bigger side buttons that can be automatically soldered
- MEMS microphone instead of electret
- spring contacts speaker with speaker enclosure formed by the case & PCB
- spring contacts rumbler
- battery connector
- new headphone detection circuit

> Front buttons are amazing, side buttons are actually worse. MEMS microphone works.Spring contacts and speaker works too, spring contacts for the rumbler works as well, but the rumbler can no longer be purchased by LCSC. Battery connector is great, but ideally would be a bit further away for the wire. The headphone detection does *not* work.

## MkIII version 3.1 - Dec 2026

> TODO

> This is the xmas 25 version.

## MkIII version 3.0 (development board) 

> TODO

## MkII version 2.3 - 19/6/24

Fixes the sound & charging problems. Charge enable is wired to the other end of the charge programming resistor so leaving it floating disables charging and setting it low enables charging by providing path to ground with no voltage leaking when disabled.

However in this version the flaw with AVR running from VCC becomes apparent as with some chargers & devices the difference of voltage between AVR and 3.3V for I2C becomes too high and chip communication does not work when DC power is connected. 

> This is the version intended for xmas 24. 

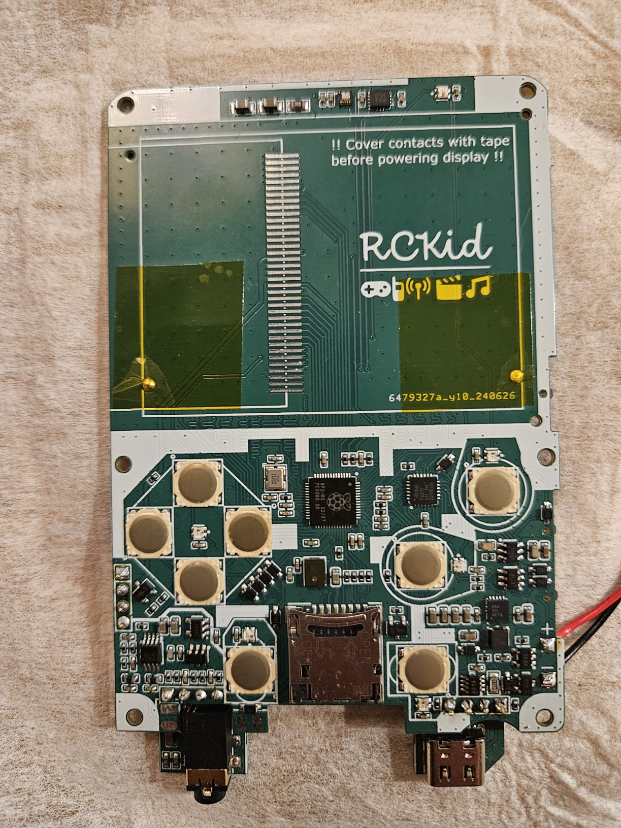
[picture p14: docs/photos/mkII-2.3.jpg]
mkII-2.3


## MkII version 2.2 - 9/3/24

Second iteration and my development device for a long time. Has modern layout, small screw holes, unified buttons and optimized layout. Small RGBs, fixed voltage comversion. Faulty speaker connection so speaker sound is extremely low volume. Faulty charging enable connection where the charge program resistor always goes to ground and charge en pin is wired directly to the charge en pin of the charger, thus leaving charge en to float enables charging and setting it high disables charging. This leaks voltage to the charger and through the charger to the VCC line which partially opens the VBATT/VCC switching mosfet lowering battery voltage. Contains INA219 for current measurement. 

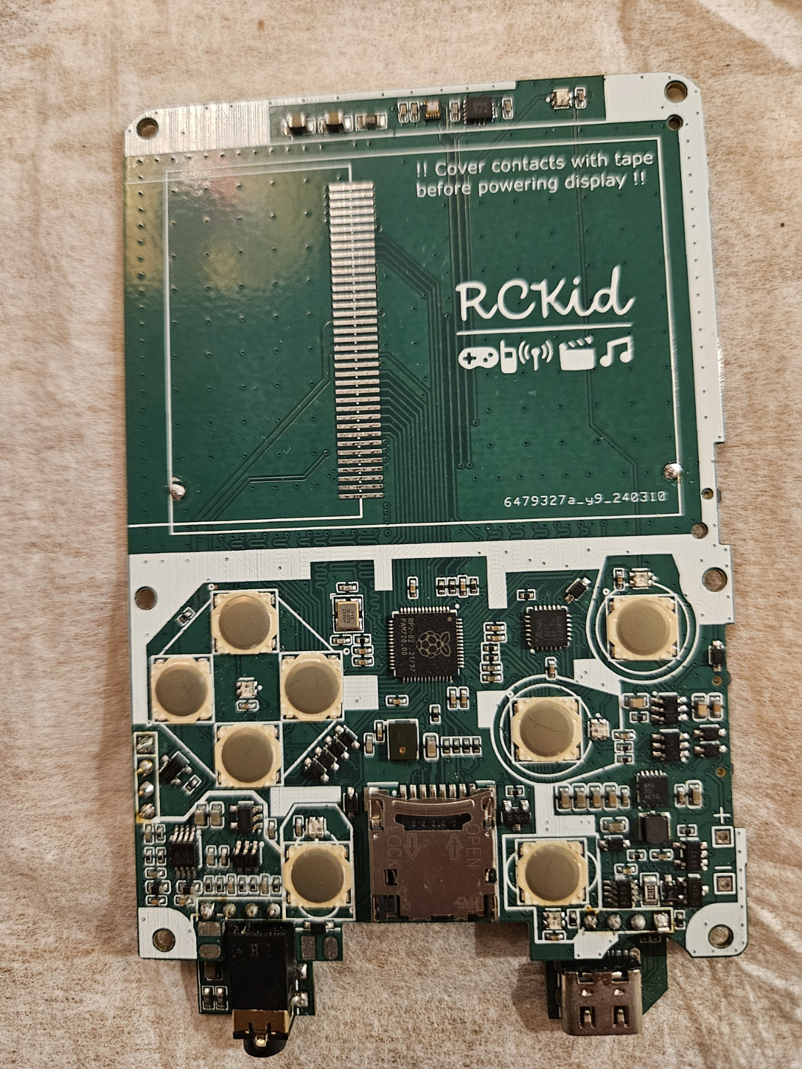
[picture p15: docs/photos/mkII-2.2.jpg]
mkII-2.2


## MkII version 0.3 - 29/10/23

This is the first version of MkII. PCB is immediately distinguishable by large holes for the screwposts (in newer versions the screws themselves go through the PCB), smaller size (no cutout for the speaker) and huge logo on the back. This was the first prototype with RP2040. Contains magnetometer and humidity sensor onboard and large Neopixel LEDs. Voltage converter between RGB and AVR did not work properly and the LEDs only worked on large enough vcc/vbatt.

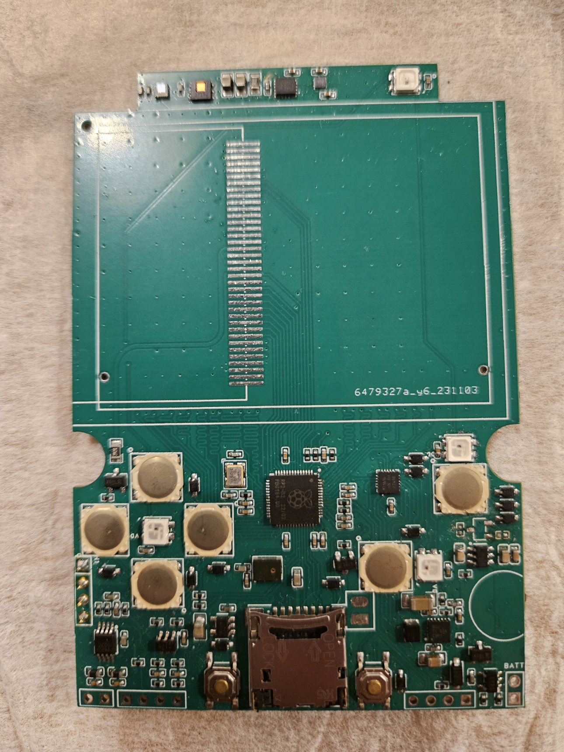
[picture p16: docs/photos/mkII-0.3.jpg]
mkII-0.3


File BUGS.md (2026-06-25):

# Interesting Bugs I Met

## 25/6/2026

In the past, debugging has been pain: The SWD, while really useful, requires an SWD probe(*), which I do not always have with me. I have baked UART over USB into the firmware on RP2350 so that every time the device is connected to a PC and running, a new COM port appears and can be monitored. This is great because **any** computer can now debug the device.

But it comes with its own set of problems - namely every device restart disconnects and reconnects the port and so it is almost impossible to capture the initialization phase. The USB layer is also code heavy so if things break big time (like a hardfault, infinite loop, etc.) the USB device stops working. 

And of course, this does not help with debugging the AVR. 

I have thus designed special cartridges which had GPIOs out that could act as HW UART on RP2350, so with external UART to USB I could monitor the debug messages in a lot more detail. For the AVR I made sure that the AVR IRQ line (which AVR could use to signal to RP2350 HW change) was conveniently the TX pin of AVR's UART connected to RX pin of RP2350's UART so it could double-duty as AVR debug uart viewable by RP2350. Cool, except a lot of stuff happens on the AVR when the RP2350 is off:(

So Beaver King version changed this. I have ditched the AVR IRQ pin entirely (RP2350 polls every frame) and I have used the pins for dedicated AVR UART TX and RP2350 UART TX that go to the debug header on the device directly(2*):

         SWD -- SWD data
         SWC -- SWD clock
         RTX -- RP2350 UART TX for debugging
         ATX -- AVR UART TX for debugging
    UPDI GND -- GND and AVR UPDI pin

This is great! I have readily available very reasonable logging from both chips and I am using it all the time.Debugging has been a breeze with the latest version. **Until I have reached very weird bugs**, to name a few:

- settings cannot be read from the AVR on startup
- brightness cannot be set on startup
- when you press a key, sometimes you get rumble feedback, sometimes not
- when you press a key the lights do not work, sometimes (a key should light up when pressed)
- when you press *some* keys (DPAD specifically), there is a *loong* delay between the rumble and key press

The last manifestation helped me crack this: One difference the DPAD has compared to other buttons is that it is being lit by 4 LEDs, not just 1. So that means 4x the number of I2C messages RP2350 has to send. Maybe the I2C was a culprit.

But the code is essentially the same as the previous version, especially in the sensitive routines (interrupts on both AVR and RP2350). So what could go wrong? Then I realized it: 

The super reliable UART is synchronous. That means that code will not move further *until* the required data is transmitted. I2C is slow, but compared to it, the UART is much slower. Every time I send I2C message to the AVR the AVR will dutifully acknowledge this on the UART lines, even if I am not listening. And this causes a very long delay between receiving the message, and processing the message. And the AVR can only process one message at a time, it sends NACKs when new master write is requested, while operation is still being performed (as the new data would overwrite the previous command in the buffer):

    // master requests to write data itself. ACK if there is no pending I2C message, NACK otherwise. The buffer is reset to 
    } else if ((status & I2C_START_MASK) == I2C_START_RX) {
        if (i2cCommandReady_) {
            TWI0.SCTRLB = TWI_ACKACT_NACK_gc | TWI_SCMD_RESPONSE_gc;
        } else {
            i2cRxBytes_ = 0;
            TWI0.SCTRLB = TWI_SCMD_RESPONSE_gc;
        }

As this never happended before because no logging was enabled on AVR most of the time, I never noticed, and I never noticed that my I2C IRQ handler at the RP2350 side did not deal with TX aborts at all. But how to deal with them? 

UART is *so* slow that simply re-triggering the transaction from the IRQ after abort will be enormously wasteful and a *lot* of attempts would be needed to finally bang it through. A standard practice is to implement a backoff strategy where after a failed attempt, we wait a bit and then try again. The amount of time we wait increases with every failed attempt. 

But we can't wait in interrupts! The only thing we can do is to somehow signal from the interrupt to the main loop that a retry is necessary, and let the main loop deal with it. Luckily the I2C already hooks to the `yield()` event that is called periodically (its our way to run sync I2C transactions), so the code changes were pretty small and neat:

    static void __not_in_flash_func(irqHandler)() {
        uint32_t cause = i2c0->hw->intr_stat;
        i2c0->hw->clr_intr;
        // disable the I2C interrupts (otherwise they might fire again immediately despite clearing, especially the TX_EMPTY one)
        i2c0->hw->intr_mask = 0;
        Transaction & t = ring_[ri_];
        // determine if the cause for the interrupt was abort, in which case see if we can retry & backoff accordingly. If no more retries are available, signal an error and if callback was provided, call the callback with -1 bytes received 
        if (cause & I2C_TX_ABORT) {
            if (attempts_++ >= RCKID_I2C_RETRIES) {
                LOG(LL_ERROR, "Unable to perform transaction");
                if (t.callback)
                    t.callback(TransactionError);
                moveToNext();
            } else {
                // to implement the backoff strategy, we must re-trigger outside of the interrupt handler. This is done by setting the retrigger time based current time and linear backoff. This is then checked in the onYield event. Because the retrigger check verifies the retrigger time not to be 0, make sure that if we accidentally landed on it move by 1us
                retrigger_ = TimePoint::now() + attempts_ * RCKID_I2C_BACKOFF_US;
                if (retrigger_ == 0)
                    retrigger_ = retrigger_ + 1;
            }
        // otherwise the transaction was performed correctly (we set the mask according to the transaction type when scheduling)
        } else {
            [...]
        }
    }

    static void onYield() {
        {
            cpu::DisableInterruptsGuard g{};
            if ((retrigger_ != 0) && (TimePoint::now() >= retrigger_)) {
                triggerTransaction();
                return;
            }
            [ bailouts if not sync transaction]
        }
        [ sync transaction handling ]
    }

The code is much more robust now[1]. That said, the lights still do not light up the way I want them to, but at least now no I2C errors and the great loggoing confirms that the messages have been sent & received properly, so I need to look elsewhere. 

(*) Luckily my old Raspberry Pi 3 dev server provides exactly that at home. It consists of the RPi with the GPIOs going out as UART, SWD, I2C and SPI wires that I can use to connect to various interfaces. For details see https://github.com/zduka/devel-server

(2*) I have of course made a mistake and used a pin that is `uart0` TX on RP2350. And this is also the only HW uart that is available on the GPIO cartridge pins, meaning that if a cartridge wants to use UART, I can't use the debugging. Next revision will have pins remapped so that the debug pin will user `uart1`.

[1] Code change in https://github.com/rc-kid/rckid/commit/951c81f5bb98e4f823b5ef69dafceb6dda2c82e5, followed by cleanup & documentation in https://github.com/rc-kid/rckid/commit/c50d153f77c747fba0d11aff8a5889c47765e66f.

## 22/6/2026

I have spent last few days bringing the v3.2 boards to life, with varying degrees of success(*). I was particularly impressed by the software. After I have been developing it in the fantasy console alone for 5 months, it worked out of the box just fine. Except every time I tried to start an application from the launcher, the device froze. Deterministically.

Past lessons remembered I reached for the SWD debugging immediately and found out the culprit quickly - when switching from update mode (where the display just receives data for the viewport forever) to command mode (where the viewport and other settings can be customized), I was disabling the PIO block for 16bit transfer and re-initializing the bitbanging for commands, I did not reinitialize the pins to SIO which resulted in a hard fault. Quick fix:)

I still can't launch apps. This time the device is stuck in endless loop waiting for the display update being done. I have looked at the interrupt handler and noticed that from it I call the callback method that refills the backbuffer with new pixels, while DMA is sending the from buffer. My worry was that the callback takes longer than the DMA transfer in some cases (such as app transitions) and interrupt in interrupt might not work on RP2350, meaning the chain will be broken and update never finished. LLMs agreed with this, so I went on restructuring the interrupt. But nothing changed. I even used up some precious AI credits on this asking for a thorough code review of the display pipeline. It found one after 11pm bug, that luckily could not have contributed (I was not supporting variable buffer sizes for DMA transfers), but still no app launches.

Then I had an idea: if I make the display speed 10x slower, then whatever the callback is doing will finish and no problem there, at least I will have proof that I am on the right path. Except with 10x slower display, the problems start *sooner*. 

So I sit back, relax, and start looking at the code, but crucially this time, I analyze the entire drawing, including the application's render function:

    void RootWidget::render() {
        if (! visible())
            return;
        // update all animations & render essentials
        Widget::renderEssentials();
        // tell the widgets that we are about to render
        onRender();
        // start rendering from rightmost column
        renderCol_ = width() - 1;
        hal::display::update([&](Color::RGB565 * & buffer, uint32_t & bufferSize) {
            if (renderCol_ < 0) {
                buffer = nullptr;
                return;
            } else if (buffer == nullptr) {
                buffer = renderBuffer_.front().data();
                bufferSize = height();
                ASSERT(bufferSize <= renderBuffer_.size());
                renderBuffer_.swap();
            }
            renderColumn(renderCol_--, 0, buffer, height());
        });
    }

    void __not_in_flash_func(irqDMADone)() {
        unsigned irqs = dma_hw->ints0;
        dma_hw->ints0 = irqs;
        if (irqs & (1u << display::dmaChannel)) {
            std::swap(display::buffer, display::backBuffer);
            std::swap(display::bufferSize, display::backBufferSize);
            // if there are pixels to send, restart the DMA immediately
            if (display::buffer != nullptr) {
                dma_channel_set_read_addr(display::dmaChannel, display::buffer, false);
                dma_channel_set_transfer_count(display::dmaChannel, display::bufferSize, true);
            }
            if (display::pixelsToWrite > 0) {
                display::cb(display::backBuffer, display::backBufferSize);
                display::pixelsToWrite -= display::bufferSize;
            } else {
                display::backBuffer = nullptr;
                display::backBufferSize = 0;
            }
        }
        [...]
    }

And luckily, the error now screams in my face:) Note how the interrupt function stops the restarts if the buffer is `nullptr`. Also note how the render routine sets the buffer to null as a precaution if rendered column is below 0 (clearly - no renderable data beyond that). The display update routine is smart and it waits until the previous frame is done before starting the new one. But the `renderCol_` belogs to the root widget and is set *before* the update is called, making the old frame decrement some of the cols (while rendering wrong ones), only to be stopped by the interrupt's own setting of the buffer to `nullptr` when the pixels to write (controlled by the driver) reaches 0. Then the new frame will start updating, but its `renderCol_` is now smaller than expected, thus will render below 0, and set the buffers to `nullptr` without ever clearing all the pixels, being stuck in infinite loop waiting for the update done without any update actually progressing.

So TL;DR: A subtle data race and two "competing" systems for determining when to stop frame update caused this problem. A fix was easy, and actually helped the code in terms of robustness and clarity as well[1].

(*) Most things work as intended. Black PCBs look great, battery connector is awesome. The new headphone detection circuit is probably not working, and not recoverable in SW. 
[1] https://github.com/rc-kid/rckid/commit/8abcdb6a27a1878940181fe24421e726923d9f64

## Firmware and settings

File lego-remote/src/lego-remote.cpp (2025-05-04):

#define DEBUG_OLED


#include "platform/platform.h"
#include "platform/peripherals/nrf24l01.h"
#include "platform/peripherals/neopixel.h"
#include "platform/peripherals/ina219.h"
#ifdef DEBUG_OLED
#include "platform/peripherals/ssd1306.h"
#endif

#include "remote/lego_remote.h"
/** Sets the connection timeout interval after which the motors turn off. Expressed in 64ths of a second. 
 */
#define CONNECTION_TIMEOUT 32  

/** In 1/4 of second. 
 */
#define CONNECTION_RESET 120

using namespace platform;
using namespace remote;

template<typename CHANNEL> struct Channel {
    typename CHANNEL::Config config;
    typename CHANNEL::Control control;
}; // Channel

/** LEGO Remote
 
    A remote controller to be used mainly with lego. Supports DC motors at 5 or 9V, servo motors, PWM channels, digital and analog inputs, neopixels and tones. 

                     -- VDD             GND --
           ML1 (WOA) -- (00) PA4   PA3 (16) -- SCK
           MR1 (WOB) -- (01) PA5   PA2 (15) -- MISO
              NRF_CS -- (02) PA6   PA1 (14) -- MOSI
            NRF_RXTX -- (03) PA7   PA0 (17) -- UPDI
    XL1 (WO2*, A0-8) -- (04) PB5   PC3 (13) -- XR1 (WO3*, A1-9)
    XL2 (WO1*, A0-9) -- (05) PB4   PC2 (12) -- XR2 (lcmp0, A1-8) -- use interrupt for waveform
             NRF_IRQ -- (06) PB3   PC1 (11) -- MR2(WOD)
        NEOPIXEL_PIN -- (07) PB2   PC0 (10) -- ML2(WOC)
                 SDA -- (08) PB1   PB0 (09) -- SCL

    Motor Channels

    2 motor channels (ML and MR) are supported. Each channel controls a single DC motor with two PWM pins for CW and CCW operation in 64 speed steps and braking & coasting. TCD is used to drive the motors' PWM signals. The motor channels use 3x4 pin connectors where the connector can select whether the pin will use 5V or 9V. The connectors can be inserted either way and have the following pinout:

        5V   +   -   9V
        SEL GND GND SEL
        9V   -   +   5V

    Configurable Channels

    4 extra channels are provided, XL1, XL2 and XR1 and XR2. The channels use a 2x3 connector that provides 5V, GND and one pin that can be configured as either of:

    - digital input
    - analog input (ADC)
    - digital output
    - analog output (PWM)

    Timers

    - 20ms intervals for the servo control (RTC)
    - 2.5ms interval for the servo control pulse (TCB0)
    - 2 8bit timers in TCA split mode
    - 1 16bit timer in TCB1 




    - RTC is used for delays
    - TCD is used for motors exclusively
    - TCB1 is used for precise servo control timing
    - TCA0 in split mode is used for the PWM channels (2 extra pins left) -- some positioned directly
    - TCB0 for tone generation (so that we can use arduino's tone function by default)

    - maye have the tone generator repurpose customIOs w/o tone stuff in the custom (i.e. mark it as out)

 */
class Remote {
public:

    static constexpr gpio::Pin NEOPIXEL_PIN = 7; 

    static constexpr gpio::Pin ML1_PIN = 0; // TCD, WOA
    static constexpr gpio::Pin MR1_PIN = 1; // TCD, WOB
    static constexpr gpio::Pin ML2_PIN = 10; // TCD, WOC
    static constexpr gpio::Pin MR2_PIN = 11; // TCD, WOD

    static constexpr gpio::Pin L1_PIN = 4; // PB5, ADC0-8, TCA-WO2* (low channel 2)
    static constexpr gpio::Pin L2_PIN = 5; // PB4, ADC0-9, TCA-WO1* (low channel 1)
    static constexpr gpio::Pin R1_PIN = 13; // PC3, ADC1-9, TCA-W03* (high channel 0)
    static constexpr gpio::Pin R2_PIN = 12; // PC2, ADC1-8, uses TCA-W0 (low channel 0) cmp and ovf interrupt to drive the pin

    static constexpr gpio::Pin NRF_CS_PIN = 2;
    static constexpr gpio::Pin NRF_RXTX_PIN = 3;
    static constexpr gpio::Pin NRF_IRQ_PIN = 6;

    static inline uint8_t rtcTicks_ = 0;

    static void initialize() {
        // set CLK_PER prescaler to 2, i.e. 10Mhz, which is the maximum the chip supports at voltages as low as 3.3V
        CCP = CCP_IOREG_gc;
        CLKCTRL.MCLKCTRLB = CLKCTRL_PEN_bm; 
        gpio::initialize();

        // clear all RGB colors, set the control LED to green & update
        gpio::output(NEOPIXEL_PIN);
        rgbColors_.clear();
        rgbColors_[0] = Color::White();
        rgbColors_.update();

        i2c::initializeMaster();
        spi::initialize();

        // set configurable channel pins to input 
        gpio::input(L1_PIN);
        gpio::input(L2_PIN);
        gpio::input(R1_PIN);
        gpio::input(R2_PIN);
        // ensure motor pins output low so that any connected motors are floating
        gpio::output(ML1_PIN);
        gpio::low(ML1_PIN);
        gpio::output(ML2_PIN);
        gpio::low(ML2_PIN);
        gpio::output(MR1_PIN);
        gpio::low(MR1_PIN);
        gpio::output(MR2_PIN);
        gpio::low(MR2_PIN);

        initializeMotorControl();
        initializeServoControl();
        initializeAnalogInputs();
        initializePWMOutputs();
        initializeAudio();
        initializePowerManagement();
#ifdef DEBUG_OLED
        initializeDebug();
#endif

        // initialize the effects timer of 64Hz (15.6ms) for RGB & tone switches
        RTC.CLKSEL = RTC_CLKSEL_INT32K_gc;
        RTC.PITCTRLA = RTC_PERIOD_CYC32_gc | RTC_PITEN_bm;
        // TODO also use this to ensure that we have a connection with the controller and turn off motors & stuff if we don't 

        

        // initialize the NRF radio
        if (!initializeRadio()) {
            rgbColors_[0] = Color::Red();
            rgbColors_.update();
            while (true) {}
        }

        // turn the white color off to signify we are done with startup
        rgbColors_.clear();
        rgbColors_.update();

        // TODO delete this when ready
        setChannelConfig(LegoRemote::CHANNEL_L1, (uint8_t*) & channel::CustomIO::Config::output());
        setChannelConfig(LegoRemote::CHANNEL_L2, (uint8_t*) & channel::CustomIO::Config::inputPullup());
        setChannelConfig(LegoRemote::CHANNEL_TONE_EFFECT, (uint8_t*) & channel::ToneEffect::Config{LegoRemote::CHANNEL_L1});
        startToneEffect(& channel::ToneEffect::Control::yelp(600, 1200, 1500));
    }

    static void loop() {
        checkDigitalIn();
        checkAnalogIn();
        servoTick();
        if (gpio::read(NRF_IRQ_PIN) == 0)
            radioIrq();
        if (RTC.PITINTFLAGS == RTC_PI_bm) {
            RTC.PITINTFLAGS = RTC_PI_bm;
            ++rtcTicks_;
            // send the delayed response
            if (responseTimeout_ > 0 && --responseTimeout_ == 0) 
                radioResponse();
            if (rtcTicks_ % 16 == 0) { // 64Hz fo effects, power and connection timeouts
                // check the power settings 
                checkPower();
                if (connTimeout_ > 0) {
                    if (connected()) {
                        if (rtcTicks_ % 10 == 0 && --connTimeout_ == 0)
                            connectionLost();
                    } else {
                        if (rtcTicks_ == 0 && --connTimeout_ == 0)
                            cpu::reset();
                    }
                }
                // do tone effect if any
                toneEffectTick();
                // do rgb effect, if any 
                rgbEffectTick();
            }
            
#ifdef DEBUG_OLED
            if (rtcTicks_ == 0 && (++dbgTimeout_ % 4) ==0) // 1Hz
                debugPrint();
#endif
        }
   
    }

#ifdef DEBUG_OLED
    /** \name Debug I2C display 
     
        Displays the messages 
     */
    //@{
    static inline SSD1306 oled_;
    static inline uint8_t dbgTimeout_ = 0;
    static inline uint16_t rx_ = 0;
    static inline uint16_t tx_ = 0;
    static inline uint16_t errors_ = 0;

    static void initializeDebug() {
        oled_.initialize128x32();
        oled_.normalMode();
        oled_.clear32();
        oled_.write(0, 0, "RX:");
        oled_.write(64, 0, "TX:");

        oled_.write(0, 1, "ML:");
        oled_.write(0, 2, "L1:");
        oled_.write(0, 3, "L2:");
        oled_.write(64, 1, "MR:");
        oled_.write(64, 2, "R1:");
        oled_.write(64, 3, "R2:");
    }

    /* */
    static void debugPrint() {
        if (paired()) {
            debugMotor(20, 1, ml_);
            debugMotor(84, 1, mr_);
            debugCustomIOChannel(20, 2, l1_.config, l1_.control, feedback_.l1);
            debugCustomIOChannel(20, 3, l2_.config, l2_.control, feedback_.l2);
            debugCustomIOChannel(84, 2, r1_.config, r1_.control, feedback_.r1);
            debugCustomIOChannel(84, 3, r2_.config, r2_.control, feedback_.r2);
            oled_.write(20, 0, rx_);
            oled_.write(84, 0, tx_);
        } else {
            char x[6] = { 0,0,0,0,0,0};
            radio_.txAddress(x);
            oled_.write(0, 1, x);
            radio_.rxAddress(x);
            oled_.write(0, 2, x);
            oled_.write(20, 0, rx_);
            oled_.write(84, 0, tx_);
        }
    }

    static void debugMotor(uint8_t x, uint8_t y, Channel<channel::Motor> & m) {
        switch (m.control.mode) {
            case channel::Motor::Mode::Coast:
                oled_.write(x, y, "coast ");
                break;
            case channel::Motor::Mode::Brake:
                oled_.write(x, y, "brake ");
                break;
            case channel::Motor::Mode::CW:
                oled_.write(x, y, "cw     ");
                oled_.write(x + 20, y, m.control.speed);
                break;
            case channel::Motor::Mode::CCW:
                oled_.write(x, y, "ccw    ");
                oled_.write(x + 20, y, m.control.speed);
                break;
        }
    }

    static void debugCustomIOChannel(uint8_t x, uint8_t y, channel::CustomIO::Config & config, channel::CustomIO::Control & control, channel::CustomIO::Feedback & feedback) {
        switch (config.mode) {
            case channel::CustomIO::Mode::DigitalIn:
               oled_.write(x, y, "di     ");
               oled_.write(x + 20, y, feedback.value);
               break;
            case channel::CustomIO::Mode::DigitalOut:
               oled_.write(x, y, "do     ");
               oled_.write(x + 20, y, control.value);
               break;
            case channel::CustomIO::Mode::AnalogIn:
               oled_.write(x, y, "ai     ");
               oled_.write(x + 20, y, feedback.value);
               break;
            case channel::CustomIO::Mode::PWM:
               oled_.write(x, y, "pwm     ");
               oled_.write(x + 20, y, control.value);
               break;
            case channel::CustomIO::Mode::Servo:
               oled_.write(x, y, "pwm     ");
               oled_.write(x + 20, y, control.value);
               break;
        }
    }

    //@}
#endif

    /** \name Power Management 
     */
    //@{

    static inline INA219 iSenseTotal_{0x40};
    static inline INA219 iSenseML_{0x44};
    static inline INA219 iSenseMR_{0x45};

    static void initializePowerManagement() {
        // 8mOhm for 10Amps max resolution in mA
        iSenseTotal_.initialize(INA219::Gain::mv_80, 8);
        /*
        // for the motors, we take 4mOhms for 5Amps max resolution
        iSenseML_.initialize(INA219::Gain::mv_80, 4);
        iSenseMR_.initialize(INA219::Gain::mv_80, 4);
        */
    }

    static void checkPower() {
        uint16_t iTotal = iSenseTotal_.current();
        /*
        uint16_t iML = iSenseML_.current();
        uint16_t iMR = iSenseMR_.current();
        */
    }

    static void activate() {

    }

    static void deactivate() {
        //feedback_.device.setActive(false);
        // TODO do stuff fere
        //setMotorL(channel::Motor::Control::Coast());
        //setMotorR(channel::Motor::Control::Coast());
        // TODO turn off the rest

    }

    //@}

    /** \name Radio comms
     
        
     */
    //@{
    static inline NRF24L01 radio_{NRF_CS_PIN, NRF_RXTX_PIN};
    static inline bool transmitting_ = false;
    static inline uint8_t rxBuffer_[32];
    static inline uint8_t txBuffer_[32];
    static inline uint8_t errorBuffer_[32];
    static inline uint8_t errorIndex_; 
    static inline uint8_t * response_;
    static inline uint8_t responseTimeout_ = 0;
    static inline uint16_t connTimeout_ = 0;
    static inline uint8_t controller_[] = { 0, 0, 0, 0, 0};
    static inline uint16_t deviceId_;
    static inline char deviceName_[16];

    /** Initializes the radio and enters the receiver mode.
     */
    static bool initializeRadio() {
        if (!radio_.initialize(msg::DefaultAddress, msg::DefaultAddress, msg::DefaultChannel))
            return false;
        radio_.standby();
        radio_.enableReceiver();
        errorBuffer_[0] = msg::Error::ID;
        deviceId_ = 12345;
        memcpy(deviceName_, "LegoRemote", 11);
        return true;
    }

    static bool paired() { return controller_[0] != 0; }

    static bool connected() { return controller_[0] != 0 && ! feedback_.device.connectionLost(); }

    static bool isPairedController(uint8_t const * name) {
        if (controller_[0] == 0)
            return false;
        for (uint8_t i = 0; i < 5; ++i)
            if (controller_[i] != name[i])
                return false;
        return true;
    }

    static void error(msg::ErrorKind err, uint8_t data = 0) {
        errorBuffer_[errorIndex_++] = static_cast<uint8_t>(err);
        errorBuffer_[errorIndex_++] = data;
        // tentatively write the end of error info after this one 
        if (errorIndex_ < 32)
            errorBuffer_[errorIndex_] = 0; 
    } 

    /** Receive command, process it and optionally send a reply.
     */
    static void radioIrq() {
        
        if (transmitting_) {
            radio_.clearIrq();
            NRF24L01::FifoStatus fifo = radio_.getFifoStatus();
            if (fifo.txEmpty()) {
                radio_.standby();
                radio_.enableReceiver();
                transmitting_ = false;
                // if the rx fifo is empty, we can quit immediately and will be notified of the next message by the IRQ, otherwise if there is something continue to the receive check and message processing to ensure the message will be processes (the IRQ is lost by the above clear action)
                if (fifo.rxEmpty())
                    return;
            } else {
                return;
            }
        } else {
            radio_.clearDataReadyIrq();
        }
        // try processing the message, if any
        if  (radio_.receive(rxBuffer_, 32)) {
#if (defined DEBUG_OLED)
            ++rx_;
#endif
            // set the response to txBuffer and load with NOP message (which we won't transmit if not changed)
            txBuffer_[0] = msg::Nop::ID;
            response_ = txBuffer_;
            // reset the error size so that we know whether to send it or not
            errorIndex_ = 1;
            if (!paired() && rxBuffer_[0] > msg::Pair::ID) {
                error(msg::ErrorKind::DeviceNotPaired, rxBuffer_[0]);
            } else {
                switch (rxBuffer_[0]) {
                    // set the tx address to the one provided in the request and then send the information 
                    case msg::RequestDeviceInfo::ID: {
                        // TODO add a random delay(?)
                        cpu::delayMs(100);
                        uint8_t * name = reinterpret_cast<msg::RequestDeviceInfo const *>(rxBuffer_)->controllerAddress;
                        if (!connected() || isPairedController(name)) {
                            radio_.setTxAddress(name);
                            new (txBuffer_) msg::DeviceInfo{LegoRemote::NUM_CHANNELS, deviceId_, deviceName_};
                        } 
                        break;
                    }
                    // reset the rx and tx addresses to default and clear the pairing flag
                    case msg::Reset::ID: {
                        uint8_t * name = reinterpret_cast<msg::Reset const *>(rxBuffer_)->controllerAddress;
                        if (!paired() || isPairedController(name)) {
                            radio_.initialize(msg::DefaultAddress, msg::DefaultAddress, msg::DefaultChannel);
                            radio_.standby();
                            radio_.enableReceiver();
                            controller_[0] = 0; // clear pairing info
                        }
                        break;
                    }
                    // pairs the device with the controller, sets the rx and tx addresses accordingly and updates the channel as requested 
                    case msg::Pair::ID: {
                        msg::Pair const * msg = reinterpret_cast<msg::Pair const *>(rxBuffer_);
                        if (msg->deviceId == deviceId_ && (strncmp(msg->deviceName, deviceName_, 15) == 0)) {
                            if (!connected() || isPairedController(msg->controllerAddress)) {
                                radio_.initialize(msg->deviceAddress, msg->controllerAddress, msg->channel);
                                radio_.standby();
                                radio_.enableReceiver();
                                // and enter the paired mode
                                for (uint8_t i = 0; i < 5; ++i)
                                    controller_[i] = msg->controllerAddress[i];
                            }
                        } 
                        // leave response at NOP
                        break;
                    }
                    // returns the channel information. This is a bit silly as we do not store the whole 32 bytes in the channel info, but we don't care if we send garbage after the final 0
                    case msg::GetChannelInfo::ID:
                        response_ = LegoRemote::CHANNEL_INFO;
                        break;
                    // returns the channel configuration for the provided channel number
                    case msg::GetChannelConfig::ID:
                        getChannelConfig(reinterpret_cast<msg::GetChannelConfig const *>(rxBuffer_)->channel);
                        break;
                    // sets the channel config for given channel    
                    case msg::SetChannelConfig::ID: {
                        msg::SetChannelConfig const * msg = reinterpret_cast<msg::SetChannelConfig const *>(rxBuffer_);
                        setChannelConfig(msg->channel, msg->config);
                        response_ = reinterpret_cast<uint8_t const *>(&feedback_);
                        break;
                    }
                    // returns the channel control for the provided channel number
                    case msg::GetChannelControl::ID:
                        getChannelControl(reinterpret_cast<msg::GetChannelControl const *>(rxBuffer_)->channel);
                        break;
                    // sets channel control for specific channels
                    case msg::SetChannelControl::ID: {
                        uint8_t i = 1;
                        while (rxBuffer_[i] != 0) {
                            uint8_t channelIndex = rxBuffer_[i++];
                            i += setChannelControl(channelIndex, rxBuffer_ + i);

                        }
                        break;
                    }
                    case msg::SetControlConsecutive::ID: {
                        msg::SetControlConsecutive const * msg = reinterpret_cast<msg::SetControlConsecutive const *>(rxBuffer_);
                        uint8_t i = 0;
                        for (uint8_t channel = msg->fromChannel, echannel = msg->fromChannel + msg->numChannels; ++channel; channel != echannel)
                           i += setChannelControl(channel, msg->data + i);
                        break; 
                    }

                    // returns feedback for the given channel
                    case msg::GetChannelFeedback::ID: 
                        getChannelFeedback(reinterpret_cast<msg::GetChannelFeedback const *>(rxBuffer_)->channel);
                        break;
                    default:    
                        error(msg::ErrorKind::InvalidCommand, rxBuffer_[0]);
                        break;
                }
                if (errorIndex_ > 1 || response_[0] != msg::Nop::ID)
                    responseTimeout_ = 7;
            }
            // reset the connection timeout
            if (connected())
                connTimeout_ = CONNECTION_TIMEOUT;
        }
    }

    static void radioResponse() {
        // send the optional error and feedback back to keep the comms
        if (errorIndex_ > 1 || response_[0] != msg::Nop::ID) {
            radio_.standby();
            if (errorIndex_ > 1) {
                radio_.transmit(errorBuffer_, 32);
#if (defined DEBUG_OLED)
                ++tx_;
#endif
            }
            if (response_[0] != msg::Nop::ID) {
                radio_.transmit(response_, 32);
#if (defined DEBUG_OLED)
                ++tx_;
#endif
            }
            transmitting_ = true;
            radio_.enableTransmitter();
        }
    }

    /** Loss of connection event. 
     */
    static void connectionLost() {
        deactivate();
        feedback_.device.setConnectionLost();
        connTimeout_ = CONNECTION_RESET;
    }

    //@}

    /** \name Channels
     
     */
    //@{


    static inline Channel<channel::Motor> ml_;
    static inline Channel<channel::Motor> mr_;
    static inline Channel<channel::CustomIO> l1_;
    static inline Channel<channel::CustomIO> r1_;
    static inline Channel<channel::CustomIO> l2_;
    static inline Channel<channel::CustomIO> r2_;
    static inline Channel<channel::ToneEffect> tone_;
    static inline Channel<channel::RGBStrip> rgb_;

    /** Feedback for all channels. 
     */
    static inline LegoRemote::Feedback feedback_;

    template<typename T>
    static void getChannelDataFrom(channel::Kind kind, T const & config) {
        txBuffer_[1] = static_cast<uint8_t>(kind);
        memcpy(txBuffer_ + 2, & config, sizeof(T));
    }
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
void loop() {
    Remote::loop();
}

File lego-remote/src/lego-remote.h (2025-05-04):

#include "remote.h"

namespace remote {

    class LegoRemote {
    public:
        static constexpr uint8_t NUM_CHANNELS = 16;

        static constexpr uint8_t CHANNEL_DEVICE = 1;
        static constexpr uint8_t CHANNEL_ML = 2;
        static constexpr uint8_t CHANNEL_MR = 3;
        static constexpr uint8_t CHANNEL_L1 = 4;
        static constexpr uint8_t CHANNEL_R1 = 5;
        static constexpr uint8_t CHANNEL_L2 = 6;
        static constexpr uint8_t CHANNEL_R2 = 7;
        static constexpr uint8_t CHANNEL_TONE_EFFECT = 8;
        static constexpr uint8_t CHANNEL_RGB_STRIP = 9;

        /** The channel info response as it is always the same. 
         */
        static constexpr uint8_t CHANNEL_INFO[] = {
            msg::ChannelInfo::ID,
            static_cast<uint8_t>(channel::Kind::Device),
            static_cast<uint8_t>(channel::Kind::Motor),
            static_cast<uint8_t>(channel::Kind::Motor),
            static_cast<uint8_t>(channel::Kind::CustomIO),
            static_cast<uint8_t>(channel::Kind::CustomIO),
            static_cast<uint8_t>(channel::Kind::CustomIO),
            static_cast<uint8_t>(channel::Kind::CustomIO),
            static_cast<uint8_t>(channel::Kind::ToneEffect),
            static_cast<uint8_t>(channel::Kind::RGBStrip),
            static_cast<uint8_t>(channel::Kind::RGBColor),
            static_cast<uint8_t>(channel::Kind::RGBColor),
            static_cast<uint8_t>(channel::Kind::RGBColor),
            static_cast<uint8_t>(channel::Kind::RGBColor),
            static_cast<uint8_t>(channel::Kind::RGBColor),
            static_cast<uint8_t>(channel::Kind::RGBColor),
            static_cast<uint8_t>(channel::Kind::RGBColor),
            static_cast<uint8_t>(channel::Kind::RGBColor),
            0 // end of channels to send 
        }; 

        /** Since the entire feedback of the Lego remote fits in 32 bytes, we can simply send all */
        class Feedback {
        private:
            uint8_t const msg = msg::FeedbackConsecutive::ID;
            uint8_t const startChannel = 1;
            uint8_t const numChannels = 9;
        public:
            channel::Device::Feedback device;
            channel::Motor::Feedback ml;
            channel::Motor::Feedback mr;
            channel::CustomIO::Feedback l1;
            channel::CustomIO::Feedback r1; 
            channel::CustomIO::Feedback l2;
            channel::CustomIO::Feedback r2;
            channel::ToneEffect::Feedback tone;
            channel::RGBStrip::Feedback rgb;
        } __attribute((__packed__)); // LegoRemote::Feedback
        
        static_assert(sizeof(Feedback) <= 32);

    }; // LegoRemote

}; // namespace remote

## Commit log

2024-08-14 Framebuffer fill test, drawing api basic. VSYNC wait.
2024-08-17 Very basic font rendering, fonts switched to 2 bpp.
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2024-09-06 Couple updates across various systems.
    UITileEngine can show tiles, Windows build fixed, filesystem updates, graphic objects hierarchy updated.
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2024-10-03 Fixes to various systems.
    [SlidingPuzzle.h]
2024-10-10 DC power detected when in sleep mode as well.
2024-10-11 Battery reporting fixed
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2024-10-12 Headphones & dc power should display properly in header.
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2024-10-12 Charging fixed for mk II v 2.2
2024-10-12 More fixes, rumbler API.
    [SlidingPuzzle.h]
2024-10-19 Easing unified with interpolation. Animation changed to timer.
2024-10-23 Galaxy invaders beginning, alarm, debug mode & bugfixes in avr.
    [GalaxyInvaders.h]
2024-11-02 Libopus added, some fixes to galaxy invaders and avr code. FixedInt updated. Display woes.
    [GalaxyInvaders.h, Sokoban.h]
2024-11-02 Some fixes to galaxy invaders
    [GalaxyInvaders.h]
2024-11-07 Some BOM, more icons & displayed in sokoban.
2024-11-10 Super basic hall of fame and an example of how to use it in tetris.
2024-11-10 Cartirdge FS works on device as well.
    Fixed cartridge flash size to 16MB and delete of nullptr.
    [Tetris.h]
2024-11-11 Added opus raw encoders and decoders from v1.
    Hall of fame fonts enlarged and table capped at 5 entries.
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2024-11-16 New mgmt works on device. PNG is too large for stack, allocates on heap. More tracing. Ability to wait for serial key press before start.
    [Tetris.h]
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2024-11-17 Slight carousel refactoring and sokoban specific version for printing extra info.
2024-11-18 Some fixes to AVR battery & charging
2024-11-21 RCKid mk II version 2.3 charging works all right.
2024-11-21 Charging fixed in v2.2 (hack). Changelog with brief description of hardware versions added.
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2024-11-24 Simple, raw frame based opus encoder and decoder.
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2024-12-07 Sliding puzzle can select images from SD card. Fixes to music player.
    [SlidingPuzzle.h]
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2024-12-11 Sliding puzzle segfault fixed, icon in main menu
    [SlidingPuzzle.h]
2024-12-13 Sound added in games, minor fixes.
    [Sokoban.h, Tetris.h]
2025-01-11 [sync] Sound added in games, minor fixes.
    Sync with power path using discrete components from mkII.
    [Tetris.h]
2025-01-14 Some more PCB layout added, FM radio and more IC integration.
2025-01-16 More work done on the mkIII PCB draft
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2025-01-19 Some more HW design information added. NiMH battery option added.
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2025-02-07 Towards primitive mkII backend - platform updates and backend template & st7789 display driver.
2025-02-09 Graphics refactoring for simpler bitmaps & color management. And towards some UI framework.
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2025-03-08 Some GBCEmulator stuff ported, updated, bugfixed. Latest mkIII hardware backups.
    [RCKid mkIII.skp]
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2025-03-16 Some more updates and fixes.
    [gbcemu.h, insns.inc.h]
2025-03-18 Added generated tests and some fixes.
    [arithmetic.cpp, gbcemu.h, insns.inc.h]
2025-03-18 All but three instructions fixed.
    Instruction tests in headers for easier maintenance and faster tooling.
    [insns.inc.h]
2025-03-18 Fixes for most of blargg tests. DAA & EI not working still
    [insns.inc.h]
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2025-03-19 BKPT instruction added to enable testing. Tests fixed.
    [gbcemu.h, insns.inc.h]
2025-03-19 Timer fixed.
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2025-03-20 DAA instruction fixed. STOP updated. All blargg's instruction test roms pass.
    [insns.inc.h]
2025-03-21 VBlank interrupt fixed.
2025-03-21 Display rendering offset fixed & small updates.
    [gbcemu.h]
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2025-03-25 Frame rate control for GBCEmu to stay at 60 fps
2025-03-25 Stack push & pop for call, ret and interrupts refactored.
2025-03-27 Timer fixes for gbcemu
    [gbcemu.h, insns.inc.h]
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2025-03-29 Buttons and IRQ in AVR serial debug prototypes with simple writer implementation w/o functional.
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2025-04-06 Some basic RP and AVR communications.
    AVR state better interrupt handling and seocnds int for timekeeping on rp.
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2025-04-11 Correct LCD turnoff, sprite y axis flip
    [gbcemu.h]
2025-04-13 Towards tone generation. Generic lazy buffer added, string switched to use lazy buffer.
2025-04-21 Extra writeback for BIT (HL) instruction removed.
    This had no effect as the unchanged value was written, but the extra write could lead to unexpected bank switch when used on values stored in ROM.
2025-04-22 ERAM & sprite palette fixes
    [gbcemu.h]
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2025-04-29 Main menu history & restarts. Code cleanup and memory fixes.
    [gbcemu.h]
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2025-05-11 Some investigation of the device free errors.
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2025-05-17 RGB led tested and small fixes
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2025-06-18 Arena allocation on device fixed.
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2025-07-01 Writer interface actually does not allocate on heap allowing heap allocations to be logged on the device.
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2025-07-06 Fixes to radio and i2c comms. LL_I2C loglevel added.
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2025-08-04 Sync for HW mkIII
    [RCKid mkIII.skp]
2025-08-08 Updates to hardware (case & pcb)
    [RCKid mkIII.skp]
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2025-08-27 GBCEmu catridge loading & cleanup fixes.
    [gbcemu.h]
2025-09-03 Added 3D models, logo update
    [buttons.stl, cartridge fused.stl, case bottom.stl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]
2025-09-06 Ready for mkIII prototype orders including case & cartridges with RM2 module.
    [buttons.stl, display cover.stl, top for display cover.stl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]
2025-09-10 Very crude noise channel.
    [apu.h]
2025-09-14 runModal old code removed from app, replaced with loop
    [gbcemu.h]
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2025-10-07 Some progress on the pio SPI driver for SD card, but not working yet.
2025-10-07 Button presses & releases fixed.
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2025-10-10 Can talk to the card at 20MHz, CMD9 block fix, pin drive & slew rate adjustments.
2025-10-14 AudioStream uses the new API, but problems not gone yet.
    [apu.h]
2025-10-15 Heisenbug fixed:)
    This was caused by actual heap overflow. However, any attempts and debugging it led to the bug disappearing and it demonstrated in a really weird ways where it looked like anything from miscompile to stack corruption.
    But the heap overflow was real. The optimization that only rendered the audio player frames if there was a change has the unfortunate sideffect that it bypassed the display blank wait and hence the main loop was super fast and every tick issued avr status request, which could not be serviced in time so they kept growing. Of course any slowdown in the main loop meant the avr requests were serviced just in time and the bug disappeared.
    [apu.h]
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2025-10-27 Avr version so that incompatibilities between cartridge & avr will not execute. RGB LED effects can skip ticks
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2025-10-28 Some fixes & polishing.
    GBCEmu can change colors, only games are budgeted. Settings & debug menu basics.
    [gbcemu.h]
2025-11-02 RGB LED delay in AVR removed. Radio RDS time sync when received.
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2025-11-07 [sync] mkIII stl files, some work on audio player bg task
    [cartridge fused.stl, case bottom.stl, top fused.stl]
2025-11-08 MP3 player & task improvements.
    Switching to yield() method for better decoding latency.
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2025-11-17 Towards alarm app, I2C avr bootloader copied from mkI for future rework.
2025-11-22 Will actually connect to wifi network.
    Debug prints added, mbedtls linked & configured. Actually transmission todo.
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2025-11-30 Task stopping & tick prevention.
    [gbcemu.h]
2025-12-09 Critical battery error in avr
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2025-12-30 Accelerometer, icons cleanup.
    Pedometer super basic app, but pedometer not working yet.
2025-12-31 Pedometer fixed. GBCemu game saves preserve sound.
    [apu.h]
2026-01-02 Accelerometer orientation for X axis fixed.
2026-01-04 Assertion failure fixed in home menu.
    GBCemu will allow VRAM and OAM updates at any time as the mode3 updates are not used in roms.
    [gbcemu.h]
2026-01-04 Power off interrupt & power off improvements
    When device should power off via AVR (long home press or critical battery level), the process is not immediate - first the power interrupt is set to inform RP to power off, if power off command not s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
    The power off sequence calls exit() for all apps on the stack, so that they can save their state automatically at power off. This required rewrite and simplification of the app stack and focus & blur.
2026-01-06 Budget prohibited interval, PowerOff Ack.
    Adds prohibited interval settings during which no budgeted apps can be played. This also required addition of HH:MM TinyTime variant with only 2 bytes storage.
    Adds PowerOffAck command that RP2350 uses to acknowledge power off interrupt when working normally.
2026-01-13 Towards heartbeat period interrupt.
    Basic heartbeat task, app. Minor fixes to task handling.
    [gbcemu.h]
2026-01-17 Heartbeat fixed, extended to 1hr.
    Heartbeat also resets the step counter. Interrupts are dealt with in tick() to ensure that I2C commands can be called from them. Consolidation in TinyDate reading and writing.
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2026-03-11 Noreturn for poweroff and fatal error.
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2026-03-11 Playback visualizations partially done.
    Missing time information and proper track transitions.
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2026-03-11 AudioPlayback in fantasy working.
    Timer, minor improvements & fixes. FileBrowser filters.
2026-03-11 Basic home menu assets.
    Exit moved to home menu. Poweroff and settings added too.
2026-03-11 Header improvements.
    Header can now hide on timer, audio changes update header.
2026-03-11 GBCEmu builds & will start.
    Sound and basic graphics work, memory issues left & right. Launcher main menu options.
    [apu.h, gbcemu.h]
2026-03-11 Updates to header.
    Also battery added, audio simplified, fantasy mode can explicitly control mock peripherals.
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2026-03-11 AVR firmware updates.
    Basics of button matrix, power modes, ADC, etc. Mostly simplifications & cleanup of the old code for the simpler SDK v 1.0 AVR interface.
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2026-03-12 Now that we have the grand vision, I could not resist updating it:)
2026-03-27 Button object added.
    Some more prototyping of the game engine, now using butto events for game movements.
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2026-03-31 Descriptors prototype.
    New descriptors design (instead of former meta objects). The descriptors are all constexpr to stay in flash.
2026-04-12 Flashlight app ported.
    Modulo icon, Flashlight capability renamed to LED to avoid name clashes.
2026-05-02 Widget has onChange event.
    This subsumes the previous onResize as a single event called when any property change that can lead to reclaculating some visual properties other than every frame is to be executed.
2026-05-05 Button repeat fixed.
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2026-05-31 And we have extremely primite, hacky asset game editing for single sprites.
    This is just POC for in-game on-device editing capabilities, will change significantly in future - this is just for demo purposes.
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2026-06-11 Audio codec initialization. Trigger & stereo samples in configuratin fix
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2026-06-16 Fixes to AVR can power on & off.
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2026-06-21 Display bitbanging init pin init fixed.
2026-06-22 Rendering pipeline fixed.
    Was nasty bug with root widget's rendering column being reset before the previous frame update finished, which caused all kinds of ugly stuff (namely stuck rendering pipeline wirh pixels to write).
    Also simplified the pixels to write & update tracking.
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2026-07-31 Build fix & light sensor capability header.
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2026-08-05 Fixed dialog to menu back hang on device.
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2026-09-11 Speaker mute option
    Not tested on device. Useful when parents want to kill loud speakers, also useful for mk3.2 where it allows switching between speaker & headphones effectively with the broken autodetect.
2026-09-21 Launcher overlays keep launcher link for menju refreshing, etc. Friends new & delete fixed.
    [gbcemu.h]
2026-09-22 Swapped A B button lights.
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2026-10-28 I2C comms tested & fixed.
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2026-11-10 Debug and pretty printers not part of ASTs. as typecasts in language ref, not parsed yet
